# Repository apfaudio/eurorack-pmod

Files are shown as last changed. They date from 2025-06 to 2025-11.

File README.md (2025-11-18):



*Note: this repository contains Verilog examples for using Eurorack-PMOD with different FPGA boards. If you are trying to pair it with Tiliqua or Amaranth HDL, see the [quickstart guide there](https://apfaudio.github.io/tiliqua/quickstart/tlq_expander.html)*

# Eurorack PMOD

**Eurorack PMOD** is an [open hardware](https://certification.oshwa.org/de000135.html) Eurorack module that plugs directly into many FPGA boards, which makes it easy to combine the world of FPGAs and [hardware electronic music synthesis](https://en.wikipedia.org/wiki/Eurorack).

The hardware looks like this:



## How does it work? ([tutorial video](https://youtu.be/TcqFej9GK8U))
- Plug eurorack-pmod into an FPGA development board of your choice. Here is a list of [boards already supported by the examples](gateware/boards).
- Get started with some [example DSP cores](gateware/cores). Examples include calibration, sampling, effects, synthesis sources and so on. The design files can be synthesized to a bitstream using Yosys' [oss-cad-suite](https://github.com/YosysHQ/oss-cad-suite-build).

## :notes: Project Showcase :sparkles:

- **[FPGA-based neural-net waveshaper](https://matpalm.com/blog/wavenet_on_fpga/)** - (from [matpalm@](https://github.com/matpalm))
- **[Teensy 4.x I2S TDM w/ Eurorack PMOD](https://github.com/Lytrix/Teensy4-i2s-TDM)** - (from [lytrix@](https://github.com/Lytrix))
- **[8-channel USB2 soundcard](https://github.com/apfaudio/eurorack-pmod-usb-soundcard)** - mostly in Amaranth.
- **[Daisy Seed TDM for Eurorack PMOD](https://github.com/heartwerker/daisy_seed_tdm_eurorack_pmod)** - (from [heartwerker@](https://github.com/heartwerker))
- **[`apu_chord` core](https://github.com/proppy/eurorack-pmod/tree/apu_chord)** - (from [proppy@](https://github.com/proppy))
- **[Real-time DSP with Rust on LiteX](https://github.com/apfaudio/eurorack-pmod-litex)** - mostly in Rust/Migen.

# R3.5 hardware details

Some minor improvements over R3.3, with the following changes:
- Additional output mute stage: 4 JFETs controlled by the `^MUTE` pin (`PDN` pin was removed and renamed to `^MUTE` - semantics are the same as before - HIGH is unmuted).
- Improved noise performance and DC tracking by adding an additional onboard 3.3V regulator for the analog domain.
- Touch IC switched from 8-channel to 16-channel version, so that the XRESET pin is not shared with one of the touch jacks.

*Note: At this time, this Verilog repo is a bit out of date and refers to R3.3 everywhere, although I am shipping R3.5. The hardware is fully backward compatible besides the touch sensor mapping, so if you compile bitstreams for R3.3, they will work on R3.5. [See here for more details](https://apfaudio.github.io/tiliqua/quickstart/tlq_expander.html).*

# R3.3 hardware details

labelled eurorack-pmod 3.3

- 3HP module compatible with modular synthesizer systems.
    - Module depth is 35mm with both ribbon cables attached.
- [PMOD](https://en.wikipedia.org/wiki/Pmod_Interface) connector compatible with many FPGA development boards.
- 8 (4 in + 4 out) DC-coupled audio channels, 192KHz / 32bit sampling supported.
- PWM-controlled, user-programmable red/green LEDs on each output channel.
- Jack insertion detection on input & output jacks.
- Calibration EEPROM for unique ID and storing calibration data.
- [new!] Touch and proximity sensing on all unused jacks as an extra input method.
    - See the `gateware/cores/touch_cv.sv` core for an example of how to use this.

## Included examples
This repository contains a bunch of example DSP cores which are continuously being updated:
- `gateware/cores/pitch_shift.sv` - Pitch shifter
- `gateware/cores/filter.sv` - Filter (low pass + resonance)
- `gateware/cores/touch_cv.sv` - Touch sensing to CV converter
- `gateware/cores/clkdiv.sv` - Clock divider
- `gateware/cores/sampler.sv` - .wav sampler
- `gateware/cores/seqswitch.sv` - Sequential routing switch
- `gateware/cores/digital_echo.sv` - Echo / delay effect
- `gateware/cores/vca.sv` - VCA (voltage controlled amplifier)
- `gateware/cores/vco.sv` - VCO (voltage controlled oscillator)
- `gateware/cores/bitcrush.sv` - Bitcrusher

These examples can all run out of the box on the development boards listed below.

## Choosing an FPGA development board
An FPGA development board itself is NOT included! Essentially anything iCE40 or ECP5 based that has a PMOD connector will support the open-source tools and the examples in this project. Just make sure you have enough LUTS, >3K is enough to do interesting things.

The following development boards have been tested with `eurorack-pmod` and are supported by the examples in the github repository
- iCEbreaker (iCE40 based)
- [iCESugar](https://github.com/wuxx/icesugar) (iCE40 based, iCE40UP5K version)
- ECPIX-5 (ECP5 based)
- Colorlight i5 (ECP5 based)
- Colorlight i9 (ECP5 based)
- pico-ice from TinyVision (iCE40 based)
- CCGM1A1 Gatemate EVB from CologneChip - [**experimental!** see here](gateware/boards/gatemate_evb/README.md)

## PMOD Pinout

assembled eurorack-pmod module R3.3 (bottom)

The PMOD pinout is on the silkscreen on the back side of the board. Details are below. Note that Pin 1 is the SQUARE pad.

1) SDI (AK4619VN SDIN1)
2) SCL (I2C SCL for AK4619VN CODEC, EEPROM, LED + JACK IO expanders)
3) SDO (AK4619VN SDOUT1)
4) SDA (I2C SDA)
5) LRCK (CODEC clock line)
6) PDN (CODEC power down, also connected to LED output enable and JACK reset line -- HIGH means everything is on)
7) BICK (CODEC clock line)
8) MCLK (CODEC clock line)
9) GND
10) GND
11) 3V3 IN
12) 3V3 IN

## Getting Started

I have tested builds on Linux, Mac and Windows (under MSYS2). All are tested in CI.

0. Install the [OSS FPGA CAD flow](https://github.com/yosyshq/oss-cad-suite-build).
    - You may be able to get yosys / verilator from other package managers but I recommend using the [releases from YosysHQ](https://github.com/yosyshq/oss-cad-suite-build) so you're using the same binaries that CI is using.
    - On Linux, once the YosysHQ suite is installed and in PATH, you should be able to just use `make` in the gateware directory.
    - On Windows, CI is using MSYS2 with MINGW64 shell. Install MSYS2, MINGW64, extract the oss-cad-suite from YosysHQ and add it to PATH. Then you should be able to use `make` in the gateware directory.
    - Note: The gateware is automatically built and tested in CI, so for either platform it may be helpful to look at [`.github/workflows/main.yml`](.github/workflows/main.yml).

1. Build or obtain `eurorack-pmod` hardware and connect it to your FPGA development board using a ribbon cable or similar. (Double check that the pin mappings are correct, some ribbon cables will swap them on you! Default pinmaps are for the ribbon cables I shipped with hardware, you need to flip the pinmaps for a direct connection PMOD -> FPGA)
2. Try some of the examples. From the `gateware` directory, type `make` to see valid commands. By default if you do not select a CORE it will compile a bitstream with the 'mirror' core, which just sends inputs to outputs. Note, you'll need to run `git submodule update --init --recursive` from the repo root after checkout.
2. Calibrate your hardware using the process described in [`gateware/cal/cal.py`](gateware/cal/cal.py). Use this to create your own `gateware/cal/cal_mem.hex` to compensate for any DC biases in the ADCs/DACs. (this step is only necessary if you need sub-50mV accuracy on your inputs/outputs, which is the case if you are tuning oscillators, not so much if you are creating rhythm pulses.

# Project structure
The project is split into 2 directories, [`hardware`](hardware) for the PCB/panel and [`gateware`](gateware) for the FPGA source. Some interesting directories:
- [`gateware/cores`](gateware/cores): example user core implementations (i.e sequential switch, bitcrusher, filter, vco, vca, sampler etc).
- [`gateware/top.sv`](gateware/top.sv): top-level gateware with defines for selecting features.
- [`gateware/cal/cal.py`](gateware/cal/cal.py): tool used to calibrate the hardware after assembly, generating calibration memory.
- [`gateware/drivers`](gateware/drivers): driver for CODEC and I2C devices used on this board.
- [`hardware/eurorack-pmod-r3`](hardware/eurorack-pmod-r3): KiCAD design files for PCB and front panel.
- [`hardware/fab`](hardware/fab): gerber files and BOM for manufacturing the hardware.

# Manufacturing

# R3.1 Hardware (no longer manufactured)

The above README focuses on R3.3, which is currently being manufactured.

Revision R3.1 was sold out in 2023. It's no longer manufactured, however this repository still supports it if you use the `HW_REV=HW_R31` flag when building. I left some of the old photos here in case they are useful.

From the gateware perspective, there is almost no difference between R3.1 and R3.3 and so any cores should be compatible with both (unless they use new features of R3.3 e.g. touch sensitive jacks).

## R3.1 boards

assembled eurorack-pmod module R3.0 (panel)
assembled eurorack-pmod module R3.0 (top)

## R3.1 hardware details

labelled eurorack-pmod 3.0

## R3.1 technical

- 3HP module compatible with modular synthesizer systems.
    - Module depth is 47mm with both ribbon cables attached
    - This fits nicely in e.g. a 4MS POD 48X (pictured below).
- PMOD connector compatible with most FPGA development boards.
- 8 (4 in + 4 out) DC-coupled audio channels, 192KHz / 32bit sampling supported.
- PWM-controlled, user-programmable red/green LEDs on each output channel.
- Jack insertion detection on input & output jacks.
- Calibration EEPROM for unique ID and storing calibration data.
- I/O is about +/- 8V capable, wider is possible with a resistor change.

## Known limitations
- Moved to github issues

# Photos

## `eurorack-pmod` R3.1 connected to iCEBreaker
assembled eurorack-pmod module (in system)

# License

OSHW logo (https://certification.oshwa.org/de000135.html)

Hardware and gateware are released under the CERN Open-Hardware License V2 `CERN-OHL-S`, mirrored in the LICENSE text in this repository.

If you wish to license parts of this design in a commercial product without a reciprocal open-source license, or you have a ground-breaking idea for a module we could work on together, feel free to contact me directly. See sebholzapfel.com.

*Copyright (C) 2022-2024 Sebastian Holzapfel*

The above LICENSE and copyright notice does NOT apply to imported artifacts in this repository (i.e datasheets, third-party footprints).

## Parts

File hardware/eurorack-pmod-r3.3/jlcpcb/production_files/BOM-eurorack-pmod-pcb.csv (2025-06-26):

Comment | Designator | Footprint | LCSC | Quantity
2.2nF | C30 | C_0402_1005Metric | C106861 | 1
PCA9635 LED DRIVER | U10 | TSSOP-28_4.4x9.7mm_P0.65mm | C110795 | 1
56K | R19,R23,R27,R31 | R_0402_1005Metric | C114756 | 4
TCM809S (2.93V) | U6 | SOT-23 | C116736 | 1
22.0uF | C10,C11,C16,C28,C3,C4,C5,C9 | C_1206_3216Metric | C12891 | 8
PCA9557PW IO EXPANDER | U4 | TSSOP-16_4.4x5mm_P0.65mm | C141380 | 1
100nF | C1,C13,C14,C15,C17,C2,C29,C31,C32,C6,C8 | C_0603_1608Metric | C14663 | 11
FERRITE | L1,L2 | L_0603_1608Metric | C14709 | 2
220pF | C18,C19,C20,C21 | C_0402_1005Metric | C1530 | 4
24AA025UIDT EEPROM | U5 | SOT-23-6 | C2061498 | 1
Ceradiode 65V | RV1,RV2,RV3,RV4,RV5,RV6,RV7,RV8 | C_0603_1608Metric | C210791 | 8
1K | R10,R13,R16,R18,R22,R26,R30,R7 | R_0603_1608Metric | C21190 | 8
33R | R34 | R_0402_1005Metric | C25105 | 1
470R | R33 | R_0402_1005Metric | C25117 | 1
100K | R35 | R_0402_1005Metric | C25741 | 1
10K | R36 | R_0402_1005Metric | C25744 | 1
100K | R12,R15,R37,R38,R39,R40,R6,R9 | R_0603_1608Metric | C25803 | 8
4K7 | R1,R11,R14,R17,R2,R20,R21,R24,R25,R28,R29,R3,R32,R4,R5,R8 | R_0402_1005Metric | C25900 | 16
VBUS05L1 | D27,D28,D29,D30,D31,D32,D33,D34 | VISHAY-LLP1006-2M | C2649891 | 8
MMBFJ111 | Q2,Q3,Q4,Q5 | SOT-23 | C274688 | 4
1uF | C33 | C_0805_2012Metric | C28323 | 1
AUDIO JACK PJ-324M0 | J10,J11,J4,J5,J6,J7,J8,J9 | pj324m | C2884986 | 8
AK4619VN AUDIO CODEC | U1 | QFN-32-1EP_5x5mm_P0.5mm_EP3.7x3.7mm_ThermalVias | C3034747 | 1
100K | RN5,RN6,RN7 | R_Array_Convex_4x0402 | C326786 | 3
120R | RN10,RN11,RN8,RN9 | R_Array_Convex_4x0402 | C326871 | 4
LTV-357T | U11 | SO-4_4.4x3.6mm_P2.54mm | C33068 | 1
AZ1117-3.3 | U8 | SOT-89-3 | C460428 | 1
Nexperia PMEG6010CEH,115 | D1,D2 | D_SOD-123F | C493190 | 2
2.2uF | C12,C7 | C_1206_3216Metric | C50254 | 2
56p | C22,C23,C24,C25 | C_0402_1005Metric | C526981 | 4
Conn_01x14_Socket | J3 | FFC_0.5-14P_CTXJ-H2.0_1 | C5373472 | 1
560R | RN12,RN13 | R_Array_Convex_4x0402 | C695210 | 2
TL072 OP AMP | U9 | SOIC-8_3.9x4.9mm_P1.27mm | C6961 | 1
TL074 OP AMP | U2,U3 | SOIC-14_3.9x8.7mm_P1.27mm | C6963 | 2
2N7002E | Q1 | SOT-23 | C71533 | 1
14.3K | RN1,RN2,RN3,RN4 | R_Array_Convex_4x0402 | C728708 | 4
15V 200mA | F2,F3 | Fuse_0805_2012Metric | C883103 | 2
CY8CMBR3116 | U7 | QFN-24-1EP_4x4mm_P0.5mm_EP2.6x2.6mm | C914913 | 1
LED 0402 RED | D10,D12,D14,D16,D18,D4,D6,D8 | LED_0402_1005Metric | C965790 | 8
LED 0402 GREEN | D11,D13,D15,D17,D3,D5,D7,D9 | LED_0402_1005Metric | C965793 | 8

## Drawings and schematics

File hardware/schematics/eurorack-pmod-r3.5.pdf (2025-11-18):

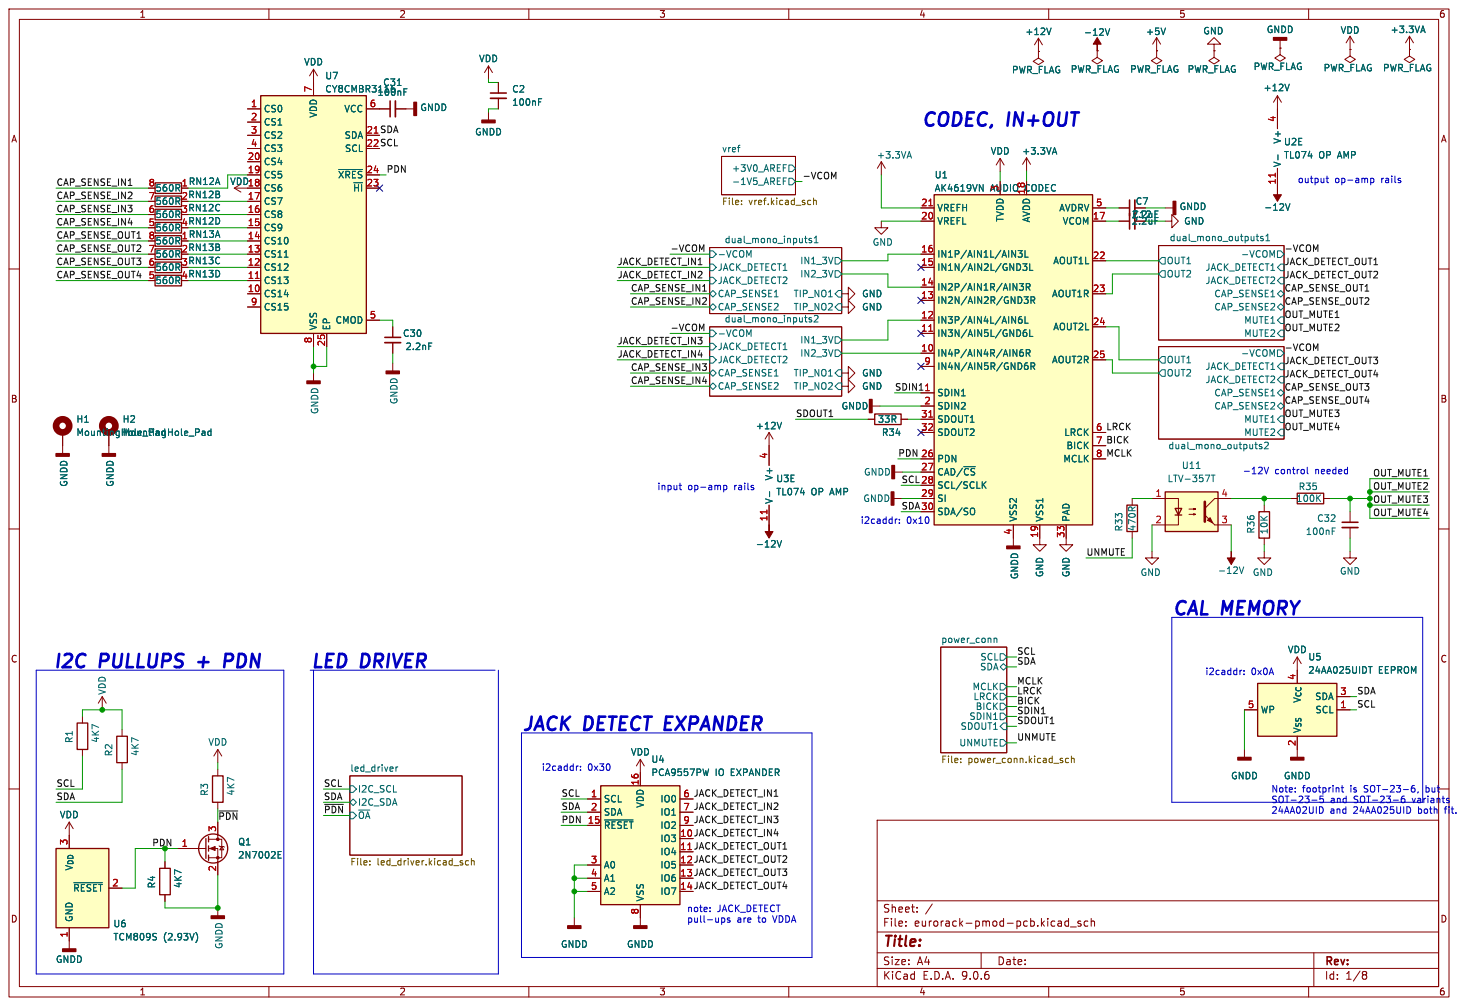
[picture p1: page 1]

8 EP 25 VCC 6 SDA 21 SCL 22 ~{XRES} 24 ~{HI}23 CMOD 5 U7 CY8CMBR3116C31

8 EP 25 VCC 6 SDA 21 SCL 22 ~{XRES} 24 ~{HI}23 CMOD 5 C31

4 AVDD 18 VSS1 19 PAD 33 AVDRV 5 VCOM 17 AOUT1L 22 AOUT1R 23 AOUT2L 24 AOUT2R 25

dual_mono_outputs1 SCL SDA UNMUTE MCLK

TL074 OP AMP GNDD GNDD
TL074 OP AMP V+

Id: 1/8 Title: File: eurorack-pmod-pcb.kicad_sch Sheet: /

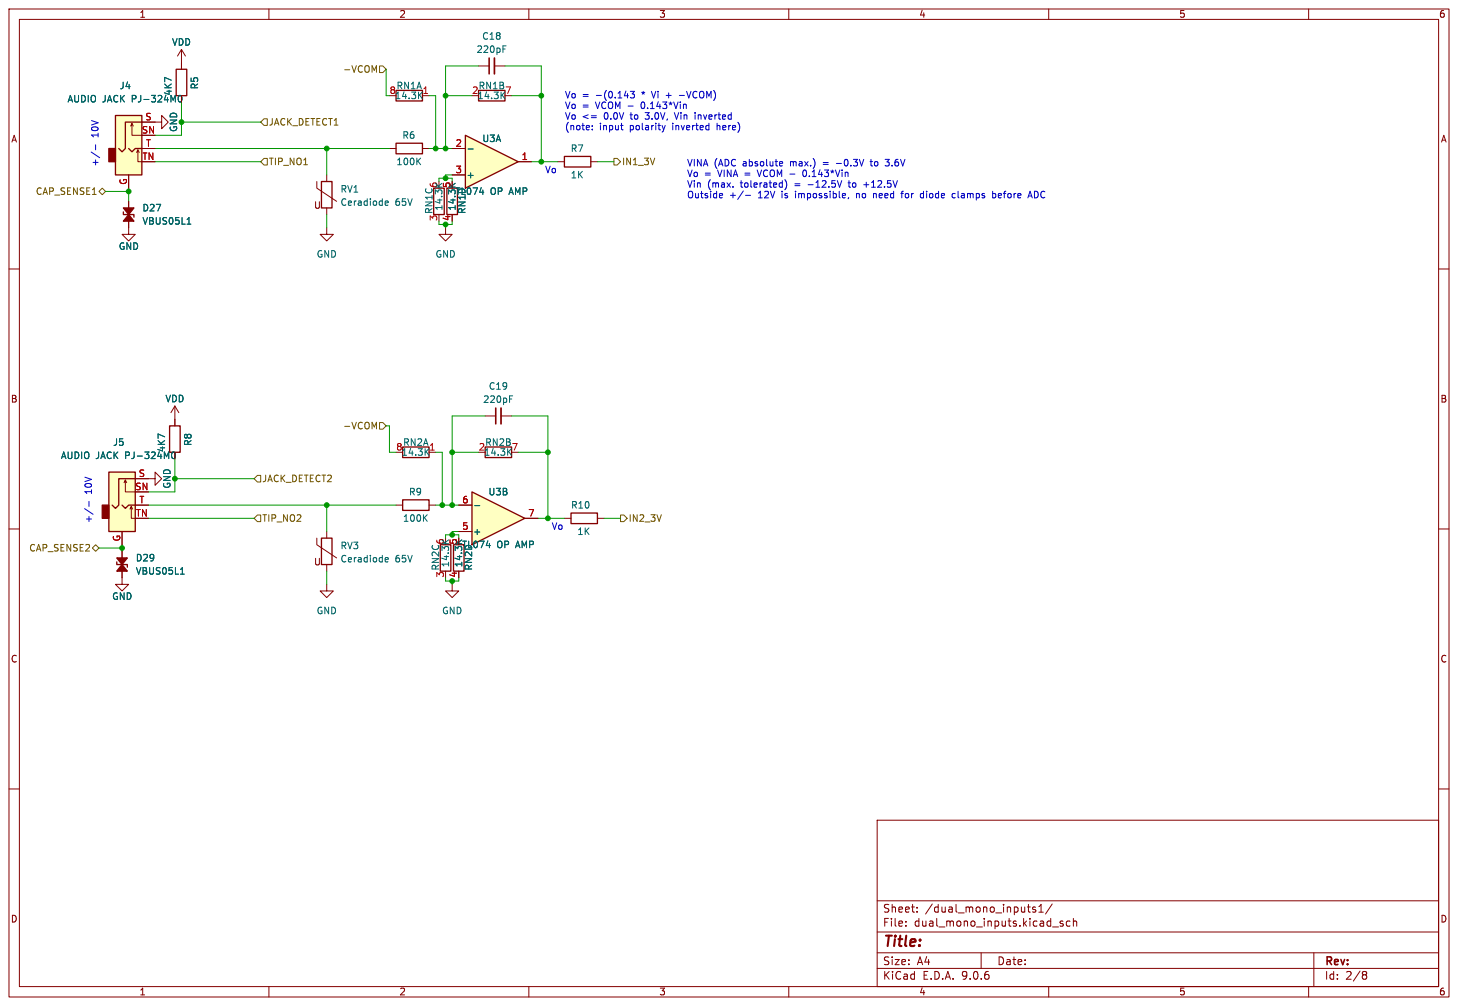
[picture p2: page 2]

Id: 2/8 Title: File: dual_mono_inputs.kicad_sch Sheet: /dual_mono_inputs1/

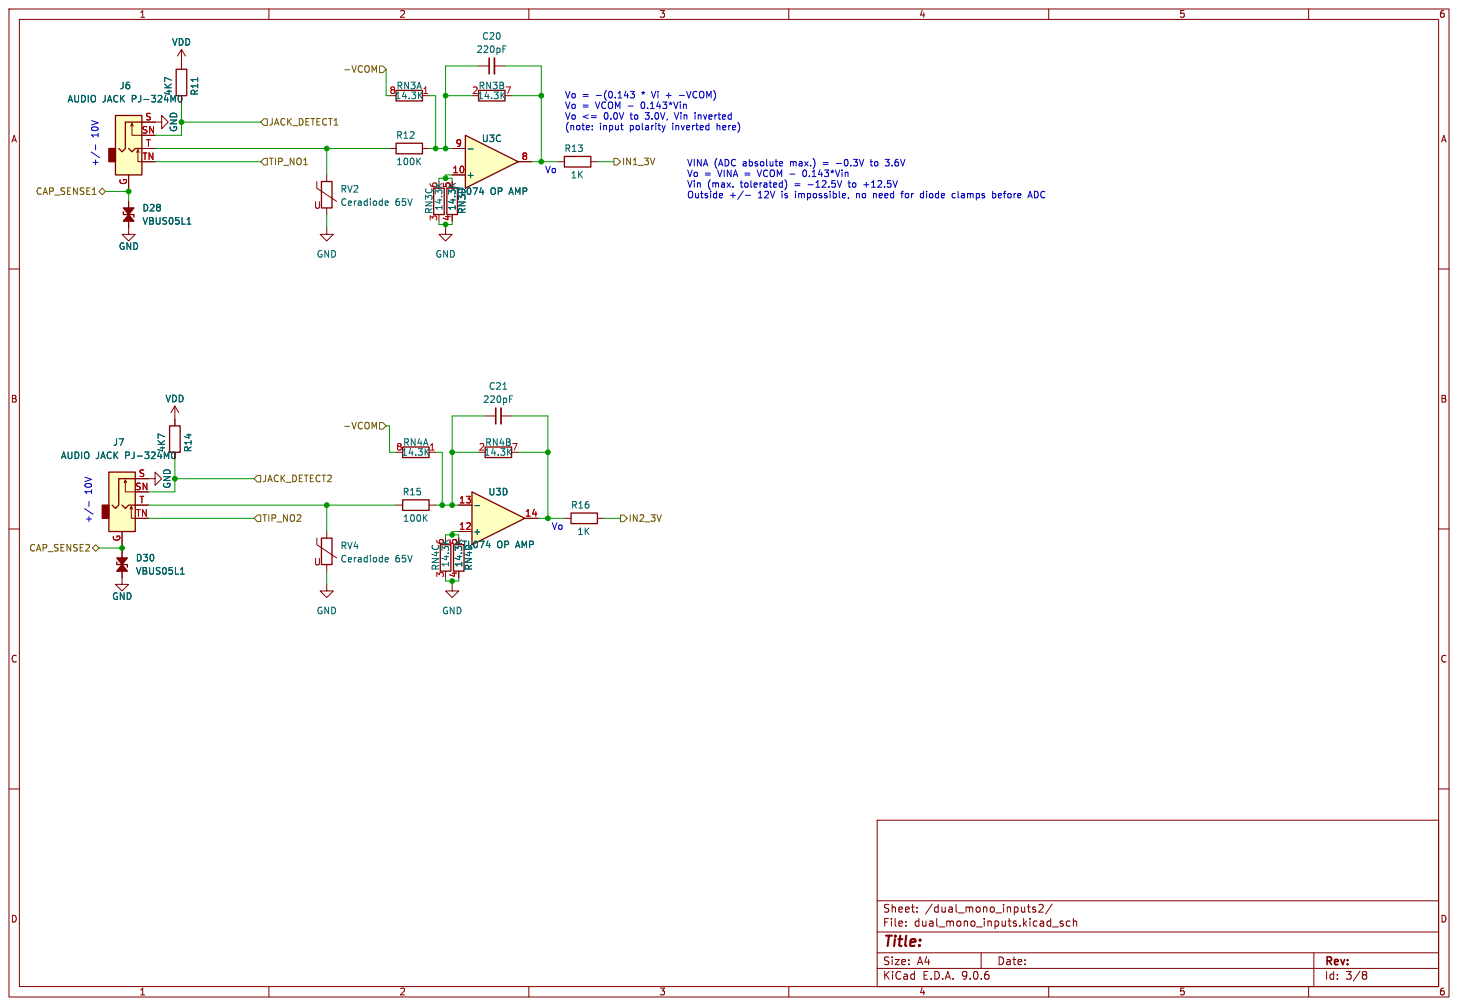
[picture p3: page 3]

Id: 3/8 Title: File: dual_mono_inputs.kicad_sch Sheet: /dual_mono_inputs2/

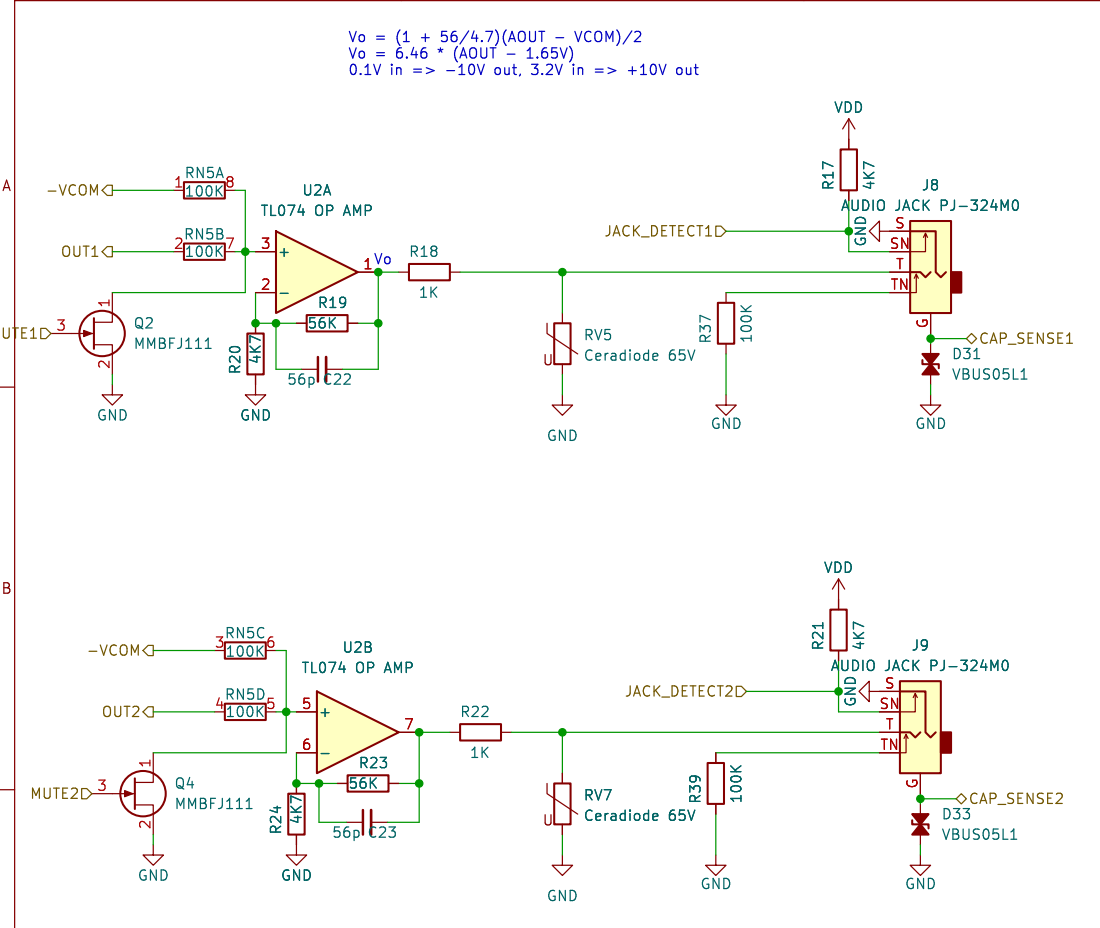
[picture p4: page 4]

Id: 4/8 Title: File: dual_mono_outputs.kicad_sch Sheet: /dual_mono_outputs1/

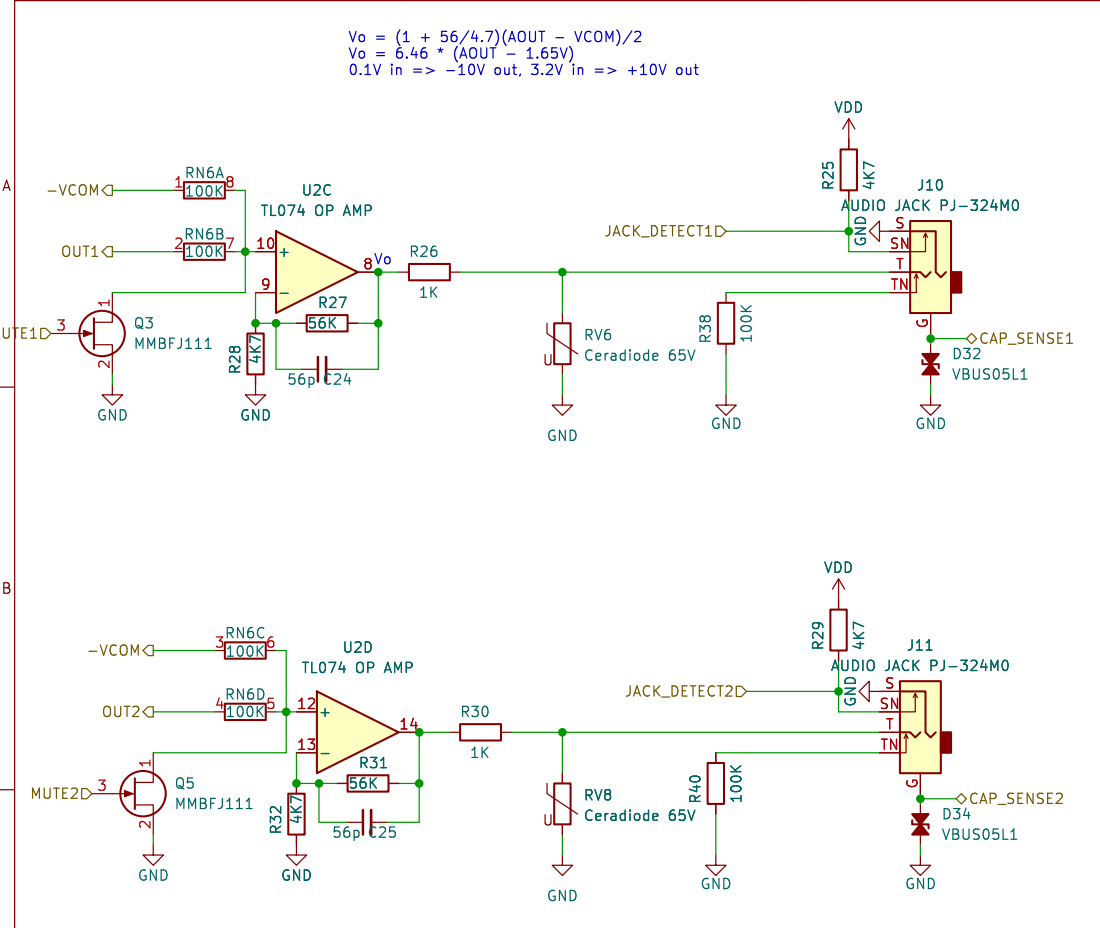
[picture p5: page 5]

Id: 5/8 Title: File: dual_mono_outputs.kicad_sch Sheet: /dual_mono_outputs2/

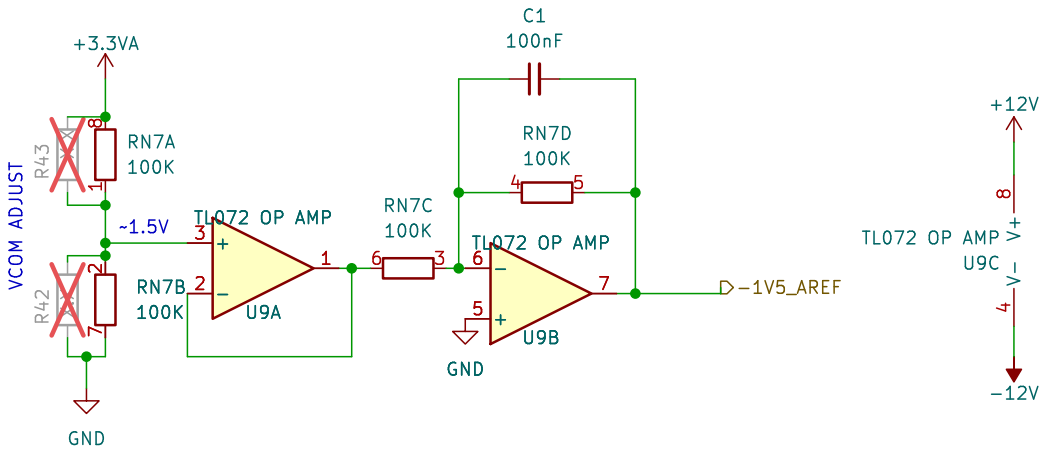
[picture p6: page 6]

Id: 6/8 Title: File: vref.kicad_sch Sheet: /vref/

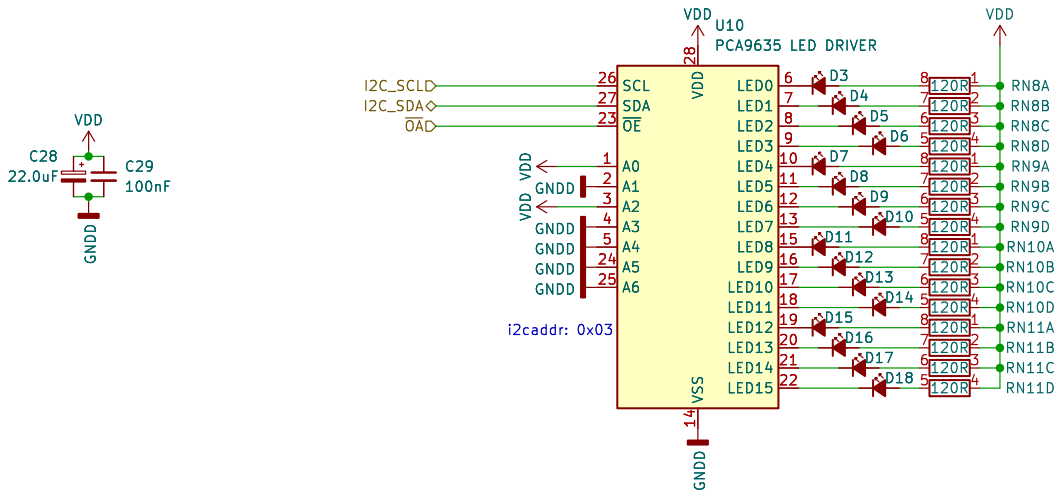
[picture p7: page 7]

Id: 7/8 Title: File: led_driver.kicad_sch Sheet: /led_driver/

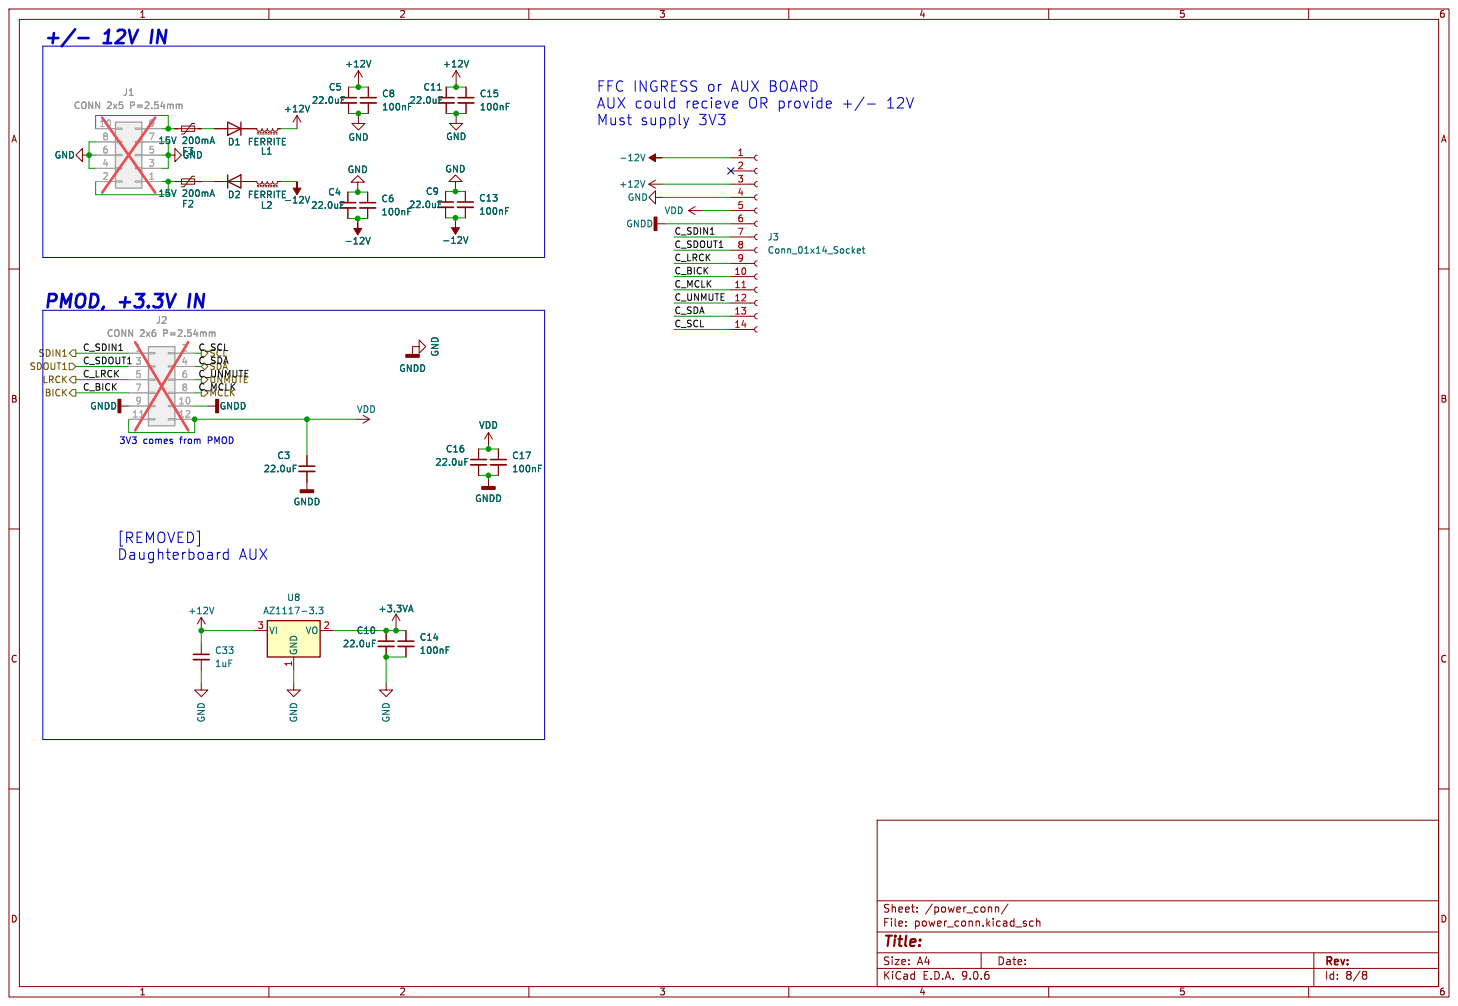
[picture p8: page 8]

FFC INGRESS or AUX BOARD
Must supply 3V3
-12VGND GNDD

Id: 8/8 Title: File: power_conn.kicad_sch Sheet: /power_conn/

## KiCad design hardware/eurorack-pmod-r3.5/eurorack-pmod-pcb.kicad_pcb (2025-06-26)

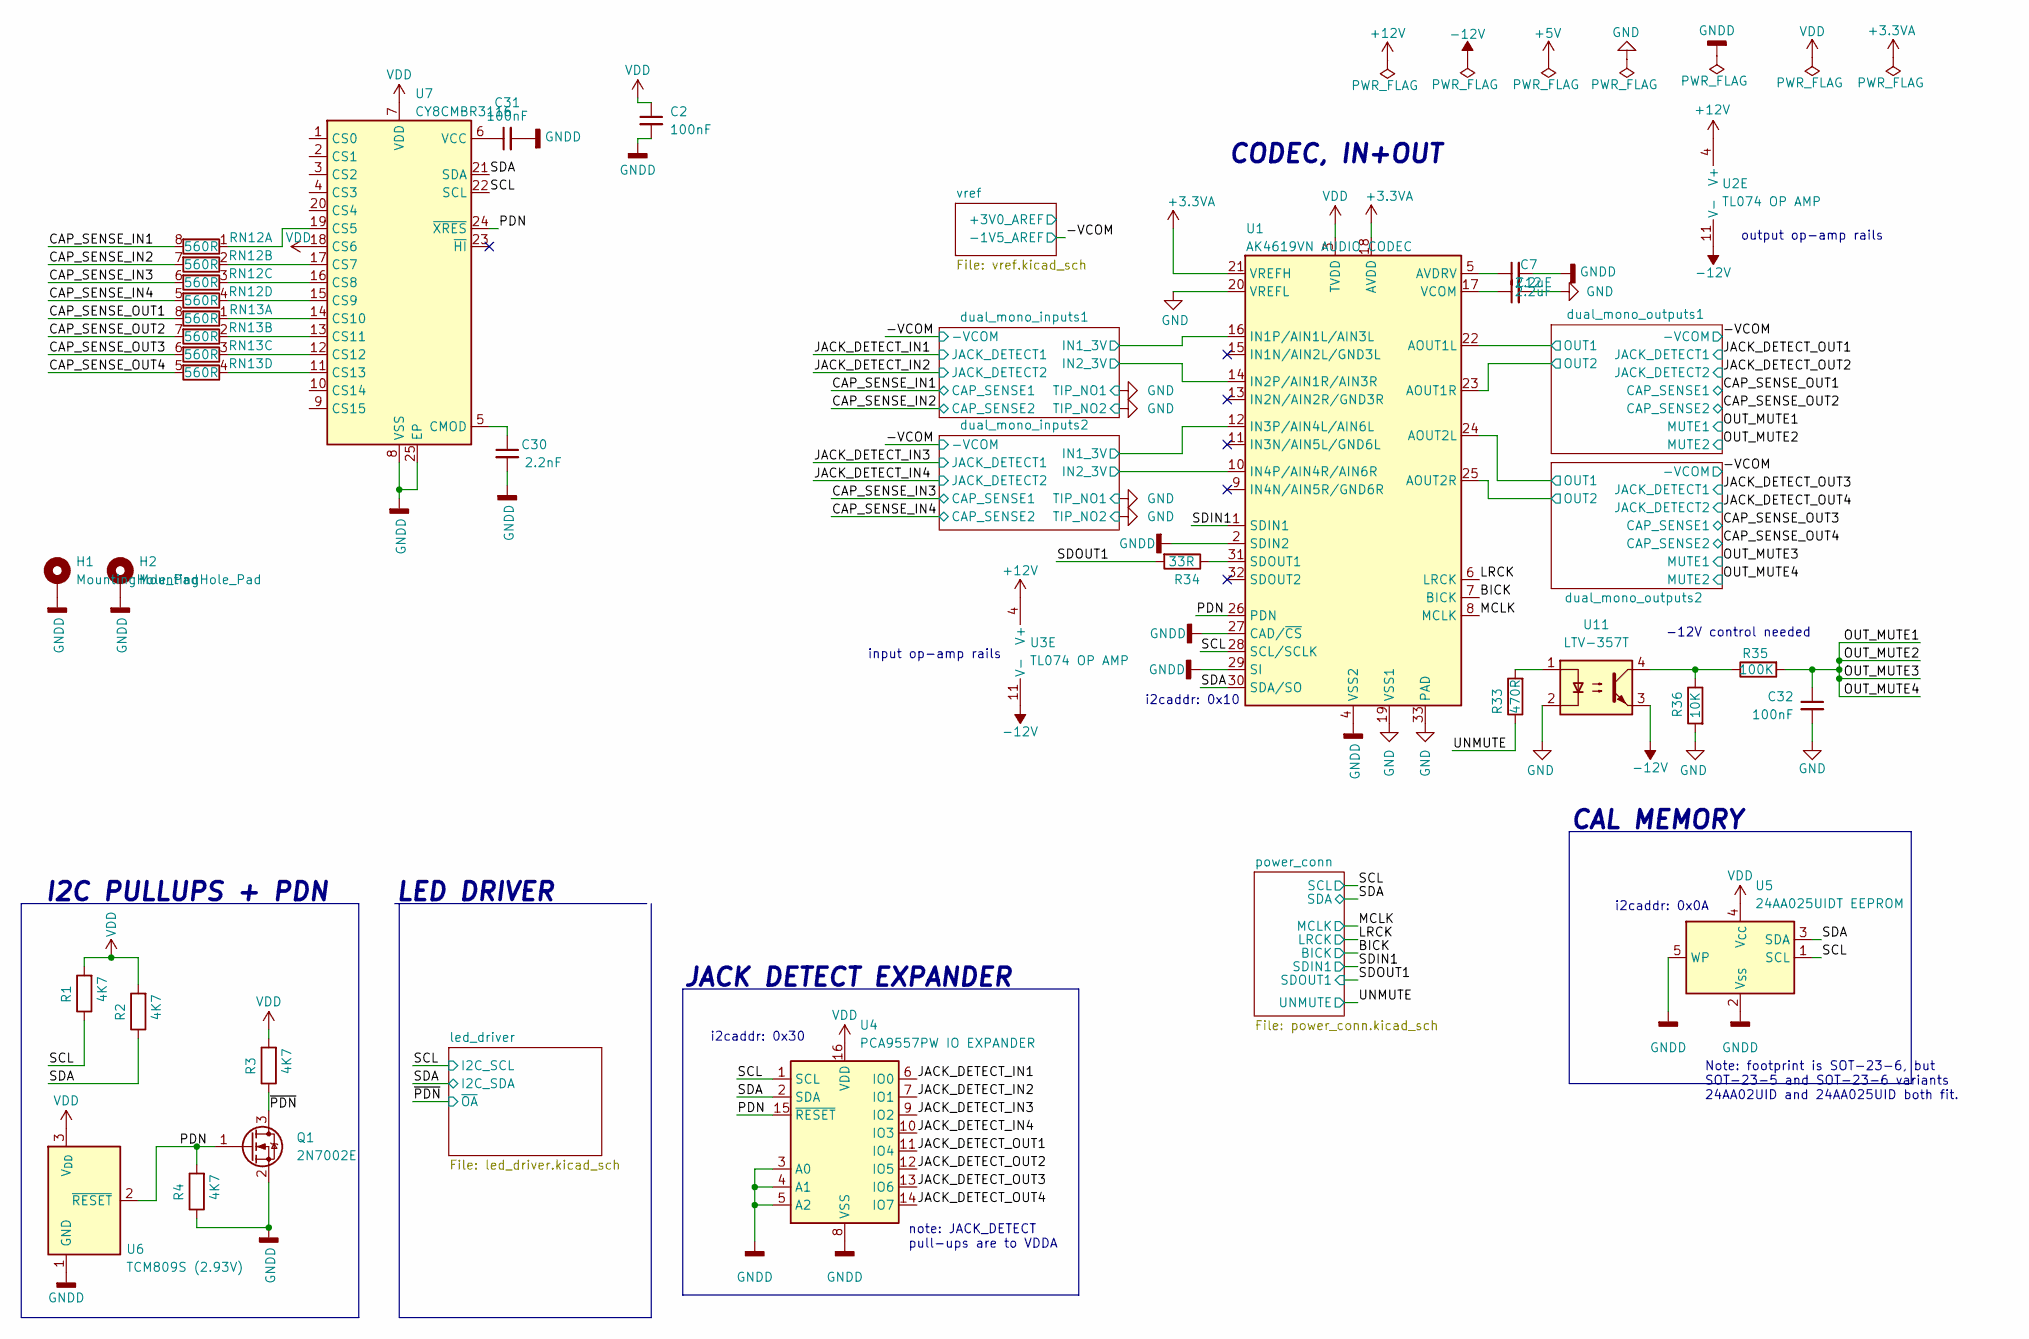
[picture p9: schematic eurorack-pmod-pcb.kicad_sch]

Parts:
C2, C31, C32: 100nF; C_0603_1608Metric; mfg# C1608X7R1E104KT000N; lcsc# C338036
C7, C12: 2.2uF; C_1206_3216Metric; lcsc# C377799
C30: 2.2nF; C_0402_1005Metric; mfg# CC0402KRX7R9BB222; lcsc# C106861
H1, H2: MountingHole_Pad
Q1: 2N7002E; SOT-23; mfg# 2N7002ET1G; lcsc# C71533
R1, R2, R3, R4: 4K7; R_0402_1005Metric; mfg# RC0402FR-074K7L; lcsc# C105871
R33: 470R; R_0402_1005Metric; LCSC C25117
R34: 33R; R_0402_1005Metric; LCSC C25105
R35: 100K; R_0402_1005Metric; LCSC C25741
R36: 10K; R_0402_1005Metric; LCSC C25744
RN12, RN13: 560R; R_Array_Convex_4x0402; mfg# YC124-JR-07560RL; lcsc# C695210
U1: AK4619VN AUDIO CODEC; QFN-32-1EP_5x5mm_P0.5mm_EP3.7x3.7mm_ThermalVias; mfg# AK4619VN; lcsc# AK4619VN
U2, U3: TL074 OP AMP; SOIC-14_3.9x8.7mm_P1.27mm; mfg# TL074CDT; lcsc# C6963
U4: PCA9557PW IO EXPANDER; TSSOP-16_4.4x5mm_P0.65mm; mfg# PCA9557PW,118; lcsc# C141380
U5: 24AA025UIDT EEPROM; SOT-23-6; mfg# 24AA025UIDT-I/OT; lcsc# C2061498
U6: TCM809S (2.93V); SOT-23; lcsc# C116736
U7: CY8CMBR3116; QFN-24-1EP_4x4mm_P0.5mm_EP2.6x2.6mm; lcsc# C914913
U11: LTV-357T; SO-4_4.4x3.6mm_P2.54mm; LCSC C33068

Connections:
+3.3VA: U1.18 (AVDD), U1.21 (VREFH); also elsewhere on the board
+12V: U2.4 (V+), U3.4 (V+); also elsewhere on the board
-12V: U2.11 (V-), U3.11 (V-), U11.3; also elsewhere on the board
/BICK: U1.7 (BICK); also elsewhere on the board
/CAP_SENSE_IN1: RN12.8 (R1.2); also elsewhere on the board
/CAP_SENSE_IN2: RN12.7 (R2.2); also elsewhere on the board
/CAP_SENSE_IN3: RN12.6 (R3.2); also elsewhere on the board
/CAP_SENSE_IN4: RN12.5 (R4.2); also elsewhere on the board
/CAP_SENSE_OUT1: RN13.8 (R1.2); also elsewhere on the board
/CAP_SENSE_OUT2: RN13.7 (R2.2); also elsewhere on the board
/CAP_SENSE_OUT3: RN13.6 (R3.2); also elsewhere on the board
/CAP_SENSE_OUT4: RN13.5 (R4.2); also elsewhere on the board
/JACK_DETECT_IN1: U4.6 (IO0); also elsewhere on the board
/JACK_DETECT_IN2: U4.7 (IO1); also elsewhere on the board
/JACK_DETECT_IN3: U4.9 (IO2); also elsewhere on the board
/JACK_DETECT_IN4: U4.10 (IO3); also elsewhere on the board
/JACK_DETECT_OUT1: U4.11 (IO4); also elsewhere on the board
/JACK_DETECT_OUT2: U4.12 (IO5); also elsewhere on the board
/JACK_DETECT_OUT3: U4.13 (IO6); also elsewhere on the board
/JACK_DETECT_OUT4: U4.14 (IO7); also elsewhere on the board
/LRCK: U1.6 (LRCK); also elsewhere on the board
/MCLK: U1.8 (MCLK); also elsewhere on the board
/OUT_MUTE1: C32.1, R35.2; also elsewhere on the board
/PDN: Q1.1 (G), R4.2, U1.26 (PDN), U4.15 (~RESET), U6.2 (~RESET), U7.24 (~XRES)
/SCL: R1.1, U1.28 (SCL/SCLK), U4.1 (SCL), U5.1 (SCL), U7.22 (SCL); also elsewhere on the board
/SDA: R2.1, U1.30 (SDA/SO), U4.2 (SDA), U5.3 (SDA), U7.21 (SDA); also elsewhere on the board
/SDIN1: U1.1 (SDIN1); also elsewhere on the board
/SDOUT1: R34.2; also elsewhere on the board
/UNMUTE: R33.1; also elsewhere on the board
/dual_mono_inputs1/IN1_3V: U1.16 (IN1P/AIN1L/AIN3L); also elsewhere on the board
/dual_mono_inputs1/IN2_3V: U1.14 (IN2P/AIN1R/AIN3R); also elsewhere on the board
/dual_mono_inputs2/IN1_3V: U1.12 (IN3P/AIN4L/AIN6L); also elsewhere on the board
/dual_mono_inputs2/IN2_3V: U1.10 (IN4P/AIN4R/AIN6R); also elsewhere on the board
/dual_mono_outputs1/OUT1: U1.22 (AOUT1L); also elsewhere on the board
/dual_mono_outputs1/OUT2: U1.23 (AOUT1R); also elsewhere on the board
/dual_mono_outputs2/OUT1: U1.24 (AOUT2L); also elsewhere on the board
/dual_mono_outputs2/OUT2: U1.25 (AOUT2R); also elsewhere on the board
/~PDN: Q1.3 (D), R3.1; also elsewhere on the board
GND: C2.2, C7.2, C12.2, C30.2, C31.2, C32.2, H1.1, H2.1, Q1.2 (S), R4.1, R36.2, U1.2 (SDIN2), U1.4 (VSS2), U1.19 (VSS1), U1.20 (VREFL), U1.27 (CAD/~CS), U1.29 (SI), U1.33 (PAD), U4.3 (A0), U4.4 (A1), U4.5 (A2), U4.8 (VSS), U5.2 (V_{SS}), U5.5 (WP), U6.1 (GND), U7.8 (VSS), U7.25 (EP), U11.2; also elsewhere on the board
unnamed 42: U2.8; also elsewhere on the board
unnamed 43: U2.14; also elsewhere on the board
unnamed 95: U2.10 (+); also elsewhere on the board
unnamed 97: U2.12 (+); also elsewhere on the board
unnamed: R33.2, U11.1
unnamed: R35.1, R36.1, U11.4
unnamed 106: U3.9 (-); also elsewhere on the board
unnamed 107: U3.8; also elsewhere on the board
unnamed 108: U3.10 (+); also elsewhere on the board
unnamed 109: U3.13 (-); also elsewhere on the board
unnamed 110: U3.14; also elsewhere on the board
unnamed 111: U3.12 (+); also elsewhere on the board
unnamed: RN12.1 (R1.1), U7.19 (CS5)
unnamed: RN12.2 (R2.1), U7.17 (CS7)
unnamed: RN12.3 (R3.1), U7.16 (CS8)
unnamed: RN12.4 (R4.1), U7.15 (CS9)
unnamed: RN13.1 (R1.1), U7.14 (CS10)
unnamed: RN13.2 (R2.1), U7.13 (CS11)
unnamed: RN13.3 (R3.1), U7.12 (CS12)
unnamed: RN13.4 (R4.1), U7.11 (CS13)
unnamed: C7.1, U1.5 (AVDRV)
unnamed: R34.1, U1.31 (SDOUT1)
unnamed: C12.1, U1.17 (VCOM)
unnamed 128: U2.9 (-); also elsewhere on the board
unnamed 129: U2.13 (-); also elsewhere on the board
unnamed: C30.1, U7.5 (CMOD)
unnamed: C31.1, U7.6 (VCC)
VDD: C2.1, R1.2, R2.2, R3.2, U1.3 (TVDD), U4.16 (VDD), U5.4 (V_{CC}), U6.3 (V_{DD}), U7.7 (VDD), U7.18 (CS6); also elsewhere on the board

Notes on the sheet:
CAL MEMORY
Note: footprint is SOT-23-6, but SOT-23-5 and SOT-23-6 variants 24AA02UID and 24AA025UID both fit.
i2caddr: 0x10
I2C PULLUPS + PDN
i2caddr: 0x30
input op-amp rails
note: JACK_DETECT pull-ups are to VDDA
JACK DETECT EXPANDER
LED DRIVER
output op-amp rails
CODEC, IN+OUT
-12V control needed
i2caddr: 0x0A

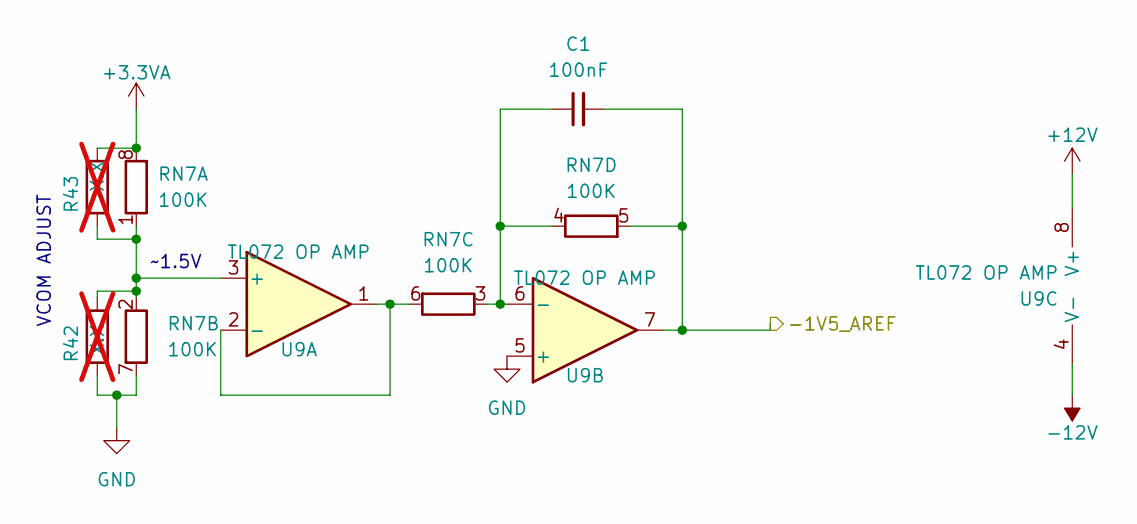
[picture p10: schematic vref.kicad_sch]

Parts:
C1: 100nF; C_0603_1608Metric; mfg# C1608X7R1E104KT000N; lcsc# C338036
R42, R43: X.X; R_0402_1005Metric; not fitted
RN7: 100K; R_Array_Convex_4x0402; mfg# YC124-FR-07100KL; lcsc# C326786
U9: TL072 OP AMP; SOIC-8_3.9x4.9mm_P1.27mm; mfg# TL072CDT; lcsc# C6961

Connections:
+3.3VA: R43.2, RN7.8 (R1.2); also elsewhere on the board
+12V: U9.8 (V+); also elsewhere on the board
-12V: U9.4 (V-); also elsewhere on the board
/-VCOM: C1.2, RN7.5 (R4.2), U9.7; also elsewhere on the board
GND: R42.1, RN7.7 (R2.2), U9.5 (+); also elsewhere on the board
unnamed: R42.2, R43.1, RN7.1 (R1.1), RN7.2 (R2.1), U9.3 (+)
unnamed: C1.1, RN7.3 (R3.1), RN7.4 (R4.1), U9.6 (-)
unnamed: RN7.6 (R3.2), U9.1, U9.2 (-)

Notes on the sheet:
~1.5V
VCOM ADJUST

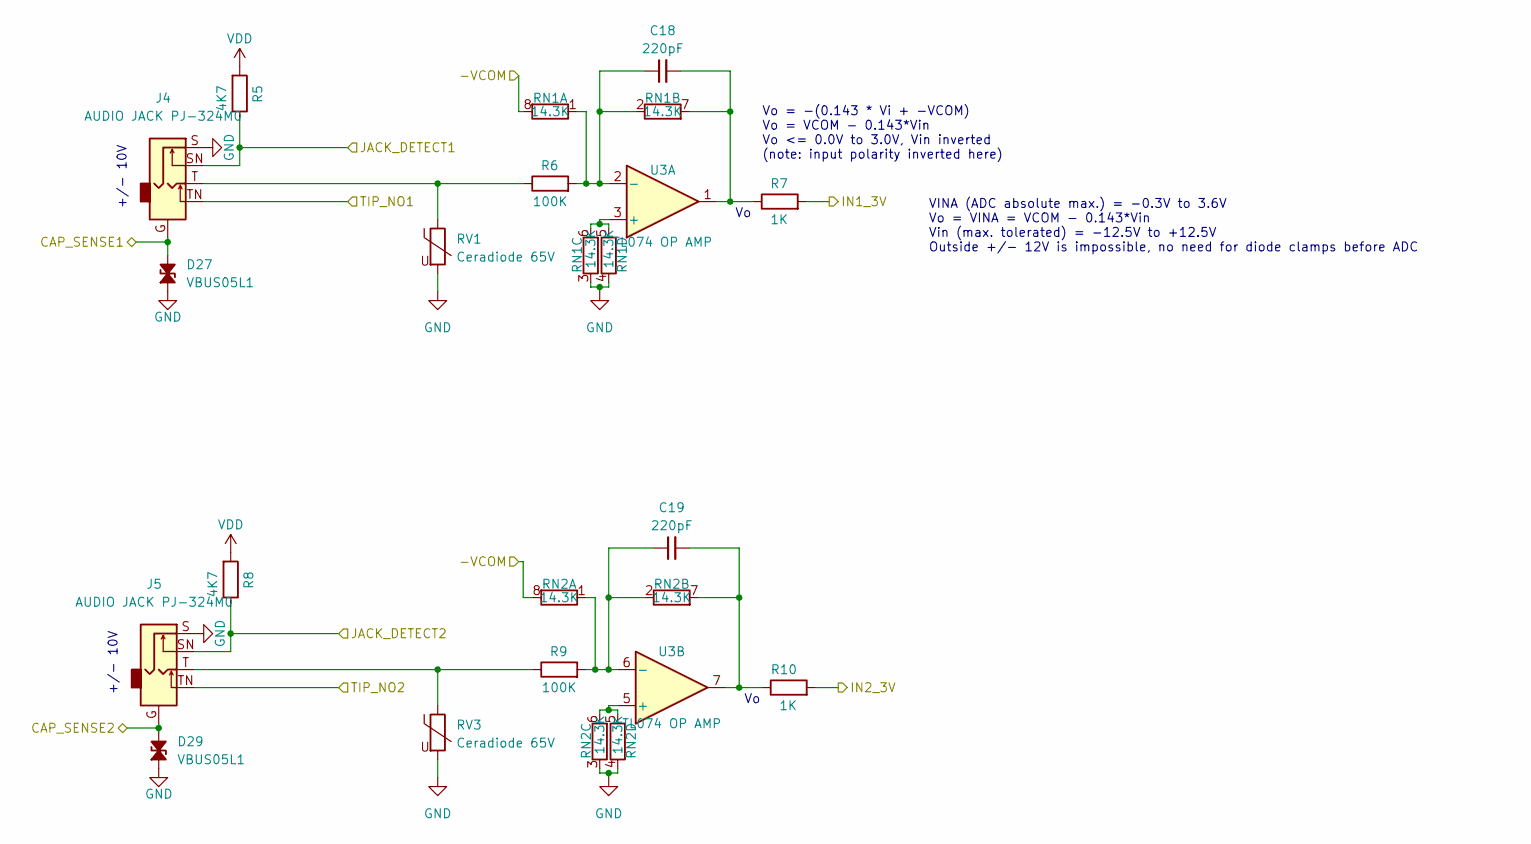
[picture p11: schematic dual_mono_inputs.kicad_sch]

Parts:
C18, C19: 220pF; C_0402_1005Metric; mfg# GRM1555C1H221JA01D; lcsc# C71693
D27, D29: VBUS05L1; VISHAY-LLP1006-2M; lcsc# C2649891
J4, J5: AUDIO JACK PJ-324M0; pj324m; mfg# PJ-324M0; lcsc# C2884986
R5, R8: 4K7; R_0402_1005Metric; mfg# RC0402FR-074K7L; lcsc# C105871
R6, R9: 100K; R_0603_1608Metric; mfg# RC0603FR-07100KL; lcsc# C14675
R7, R10: 1K; R_0603_1608Metric; mfg# RC0603FR-071KL; lcsc# C22548
RN1, RN2: 14.3K; R_Array_Convex_4x0402; mfg# YC124-FR-0714K3L; lcsc# C728708
RV1, RV3: Ceradiode 65V; C_0603_1608Metric; lcsc# C210791
U3: TL074 OP AMP; SOIC-14_3.9x8.7mm_P1.27mm; mfg# TL074CDT; lcsc# C6963

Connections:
/-VCOM: RN1.8 (R1.2), RN2.8 (R1.2); also elsewhere on the board
/CAP_SENSE_IN1: D27.2 (A2), J4.G; also elsewhere on the board
/CAP_SENSE_IN2: D29.2 (A2), J5.G; also elsewhere on the board
/JACK_DETECT_IN1: J4.SN, R5.1; also elsewhere on the board
/JACK_DETECT_IN2: J5.SN, R8.1; also elsewhere on the board
/dual_mono_inputs1/IN1_3V: R7.2; also elsewhere on the board
/dual_mono_inputs1/IN2_3V: R10.2; also elsewhere on the board
GND: D27.1 (A1), D29.1 (A1), J4.S, J4.TN, J5.S, J5.TN, RN1.3 (R3.1), RN1.4 (R4.1), RN2.3 (R3.1), RN2.4 (R4.1), RV1.2, RV3.2; also elsewhere on the board
unnamed: J4.T, R6.1, RV1.1
unnamed: J5.T, R9.1, RV3.1
unnamed: C18.1, R6.2, RN1.1 (R1.1), RN1.2 (R2.1), U3.2 (-)
unnamed: C18.2, R7.1, RN1.7 (R2.2), U3.1
unnamed: RN1.5 (R4.2), RN1.6 (R3.2), U3.3 (+)
unnamed: C19.1, R9.2, RN2.1 (R1.1), RN2.2 (R2.1), U3.6 (-)
unnamed: C19.2, R10.1, RN2.7 (R2.2), U3.7
unnamed: RN2.5 (R4.2), RN2.6 (R3.2), U3.5 (+)
unnamed 106: U3.9 (-); also elsewhere on the board
unnamed 107: U3.8; also elsewhere on the board
unnamed 108: U3.10 (+); also elsewhere on the board
unnamed 109: U3.13 (-); also elsewhere on the board
unnamed 110: U3.14; also elsewhere on the board
unnamed 111: U3.12 (+); also elsewhere on the board
VDD: R5.2, R8.2; also elsewhere on the board

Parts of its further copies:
C20, C21: 220pF; C_0402_1005Metric; mfg# GRM1555C1H221JA01D; lcsc# C71693
D28, D30: VBUS05L1; VISHAY-LLP1006-2M; lcsc# C2649891
J6, J7: AUDIO JACK PJ-324M0; pj324m; mfg# PJ-324M0; lcsc# C2884986
R11, R14: 4K7; R_0402_1005Metric; mfg# RC0402FR-074K7L; lcsc# C105871
R12, R15: 100K; R_0603_1608Metric; mfg# RC0603FR-07100KL; lcsc# C14675
R13, R16: 1K; R_0603_1608Metric; mfg# RC0603FR-071KL; lcsc# C22548
RN3, RN4: 14.3K; R_Array_Convex_4x0402; mfg# YC124-FR-0714K3L; lcsc# C728708
RV2, RV4: Ceradiode 65V; C_0603_1608Metric; lcsc# C210791

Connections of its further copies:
/-VCOM: RN3.8 (R1.2), RN4.8 (R1.2); also elsewhere on the board
/CAP_SENSE_IN3: D28.2 (A2), J6.G; also elsewhere on the board
/CAP_SENSE_IN4: D30.2 (A2), J7.G; also elsewhere on the board
/JACK_DETECT_IN3: J6.SN, R11.1; also elsewhere on the board
/JACK_DETECT_IN4: J7.SN, R14.1; also elsewhere on the board
/dual_mono_inputs2/IN1_3V: R13.2; also elsewhere on the board
/dual_mono_inputs2/IN2_3V: R16.2; also elsewhere on the board
GND: D28.1 (A1), D30.1 (A1), J6.S, J6.TN, J7.S, J7.TN, RN3.3 (R3.1), RN3.4 (R4.1), RN4.3 (R3.1), RN4.4 (R4.1), RV2.2, RV4.2; also elsewhere on the board
unnamed: J6.T, R12.1, RV2.1
unnamed: J7.T, R15.1, RV4.1
unnamed 106: C20.1, R12.2, RN3.1 (R1.1), RN3.2 (R2.1); also elsewhere on the board
unnamed 107: C20.2, R13.1, RN3.7 (R2.2); also elsewhere on the board
unnamed 108: RN3.5 (R4.2), RN3.6 (R3.2); also elsewhere on the board
unnamed 109: C21.1, R15.2, RN4.1 (R1.1), RN4.2 (R2.1); also elsewhere on the board
unnamed 110: C21.2, R16.1, RN4.7 (R2.2); also elsewhere on the board
unnamed 111: RN4.5 (R4.2), RN4.6 (R3.2); also elsewhere on the board
VDD: R11.2, R14.2; also elsewhere on the board

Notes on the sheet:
+/- 10V
Vo = -(0.143 * Vi + -VCOM) Vo = VCOM - 0.143*Vin Vo <= 0.0V to 3.0V, Vin inverted (note: input polarity inverted here)
VINA (ADC absolute max.) = -0.3V to 3.6V Vo = VINA = VCOM - 0.143*Vin Vin (max. tolerated) = -12.5V to +12.5V Outside +/- 12V is impossible, no need for diode clamps before ADC

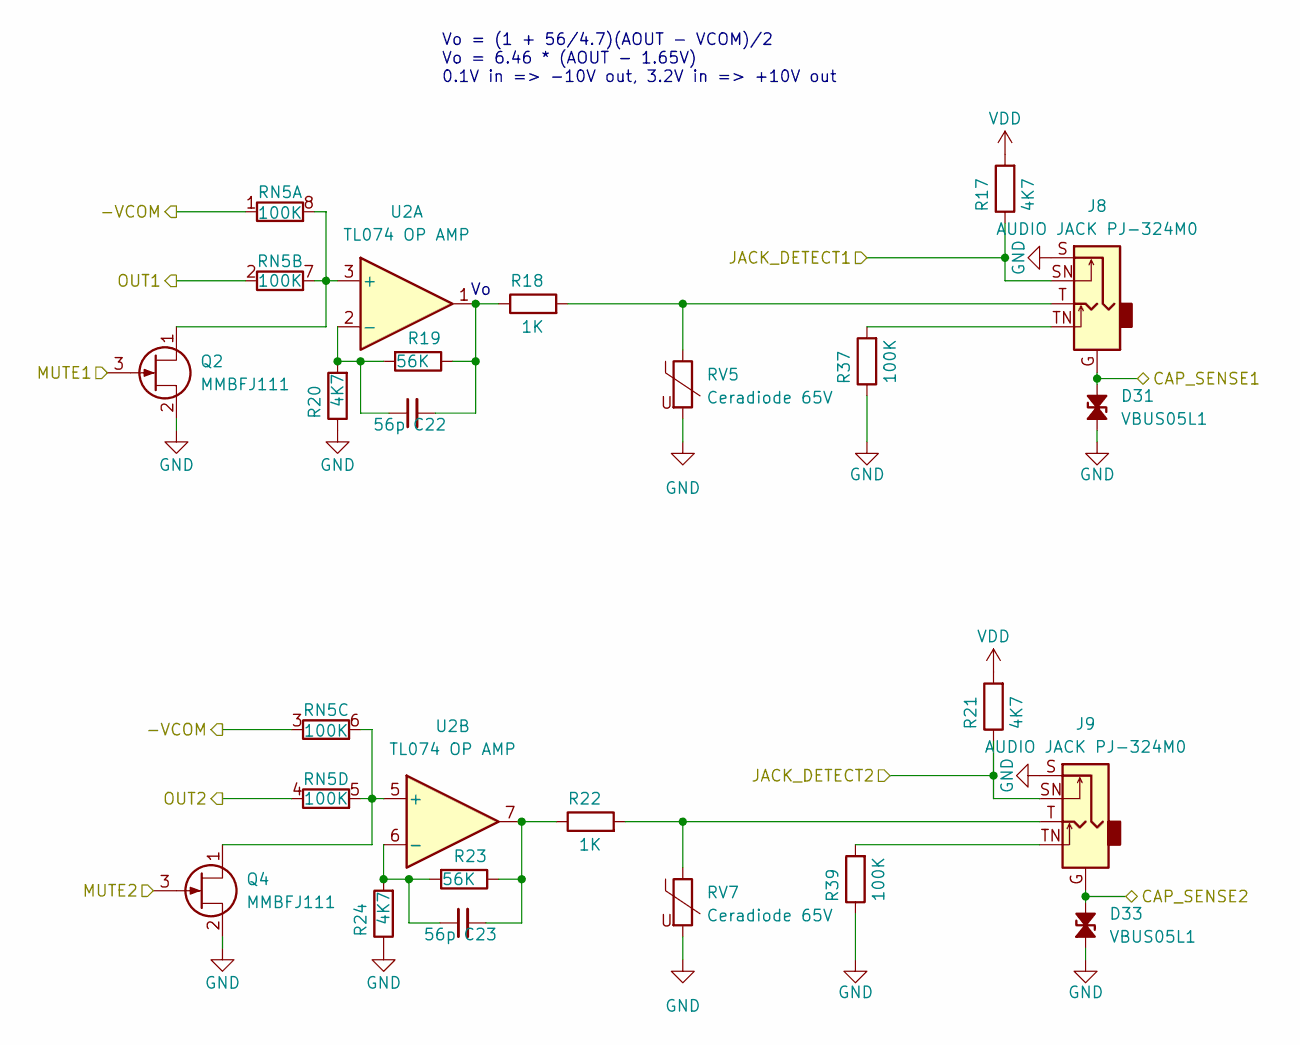
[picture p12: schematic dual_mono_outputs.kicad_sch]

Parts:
C22, C23: 56p; C_0402_1005Metric; mfg# CC0402FRNPO9BN560; lcsc# C526981
D31, D33: VBUS05L1; VISHAY-LLP1006-2M; lcsc# C2649891
J8, J9: AUDIO JACK PJ-324M0; pj324m; mfg# PJ-324M0; lcsc# C2884986
Q2, Q4: MMBFJ111; SOT-23; LCSC C274688
R17, R20, R21, R24: 4K7; R_0402_1005Metric; mfg# RC0402FR-074K7L; lcsc# C105871
R18, R22: 1K; R_0603_1608Metric; mfg# RC0603FR-071KL; lcsc# C22548
R19, R23: 56K; R_0402_1005Metric; mfg# RC0402FR-0756KL; lcsc# C114756
R37, R39: 100K; R_0603_1608Metric; mfg# RC0603FR-07100KL; lcsc# C14675
RN5: 100K; R_Array_Convex_4x0402; mfg# YC124-FR-07100KL; lcsc# C326786
RV5, RV7: Ceradiode 65V; C_0603_1608Metric; lcsc# C210791
U2: TL074 OP AMP; SOIC-14_3.9x8.7mm_P1.27mm; mfg# TL074CDT; lcsc# C6963

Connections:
/-VCOM: RN5.1 (R1.1), RN5.3 (R3.1); also elsewhere on the board
/CAP_SENSE_OUT1: D31.2 (A2), J8.G; also elsewhere on the board
/CAP_SENSE_OUT2: D33.2 (A2), J9.G; also elsewhere on the board
/JACK_DETECT_OUT1: J8.SN, R17.1; also elsewhere on the board
/JACK_DETECT_OUT2: J9.SN, R21.1; also elsewhere on the board
/OUT_MUTE1: Q2.3 (G), Q4.3 (G); also elsewhere on the board
/dual_mono_outputs1/OUT1: RN5.2 (R2.1); also elsewhere on the board
/dual_mono_outputs1/OUT2: RN5.4 (R4.1); also elsewhere on the board
GND: D31.1 (A1), D33.1 (A1), J8.S, J9.S, Q2.2 (S), Q4.2 (S), R20.1, R24.1, R37.1, R39.1, RV5.2, RV7.2; also elsewhere on the board
unnamed: C22.2, R18.1, R19.1, U2.1
unnamed: C23.2, R22.1, R23.1, U2.7
unnamed 42: U2.8; also elsewhere on the board
unnamed 43: U2.14; also elsewhere on the board
unnamed: J8.T, R18.2, RV5.1
unnamed: J8.TN, R37.2
unnamed: J9.T, R22.2, RV7.1
unnamed: J9.TN, R39.2
unnamed: Q2.1 (D), RN5.7 (R2.2), RN5.8 (R1.2), U2.3 (+)
unnamed 95: U2.10 (+); also elsewhere on the board
unnamed: Q4.1 (D), RN5.5 (R4.2), RN5.6 (R3.2), U2.5 (+)
unnamed 97: U2.12 (+); also elsewhere on the board
unnamed: C22.1, R19.2, R20.2, U2.2 (-)
unnamed: C23.1, R23.2, R24.2, U2.6 (-)
unnamed 128: U2.9 (-); also elsewhere on the board
unnamed 129: U2.13 (-); also elsewhere on the board
VDD: R17.2, R21.2; also elsewhere on the board

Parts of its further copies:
C24, C25: 56p; C_0402_1005Metric; mfg# CC0402FRNPO9BN560; lcsc# C526981
D32, D34: VBUS05L1; VISHAY-LLP1006-2M; lcsc# C2649891
J10, J11: AUDIO JACK PJ-324M0; pj324m; mfg# PJ-324M0; lcsc# C2884986
Q3, Q5: MMBFJ111; SOT-23; LCSC C274688
R25, R28, R29, R32: 4K7; R_0402_1005Metric; mfg# RC0402FR-074K7L; lcsc# C105871
R26, R30: 1K; R_0603_1608Metric; mfg# RC0603FR-071KL; lcsc# C22548
R27, R31: 56K; R_0402_1005Metric; mfg# RC0402FR-0756KL; lcsc# C114756
R38, R40: 100K; R_0603_1608Metric; mfg# RC0603FR-07100KL; lcsc# C14675
RN6: 100K; R_Array_Convex_4x0402; mfg# YC124-FR-07100KL; lcsc# C326786
RV6, RV8: Ceradiode 65V; C_0603_1608Metric; lcsc# C210791

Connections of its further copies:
/-VCOM: RN6.1 (R1.1), RN6.3 (R3.1); also elsewhere on the board
/CAP_SENSE_OUT3: D32.2 (A2), J10.G; also elsewhere on the board
/CAP_SENSE_OUT4: D34.2 (A2), J11.G; also elsewhere on the board
/JACK_DETECT_OUT3: J10.SN, R25.1; also elsewhere on the board
/JACK_DETECT_OUT4: J11.SN, R29.1; also elsewhere on the board
/OUT_MUTE1: Q3.3 (G), Q5.3 (G); also elsewhere on the board
/dual_mono_outputs2/OUT1: RN6.2 (R2.1); also elsewhere on the board
/dual_mono_outputs2/OUT2: RN6.4 (R4.1); also elsewhere on the board
GND: D32.1 (A1), D34.1 (A1), J10.S, J11.S, Q3.2 (S), Q5.2 (S), R28.1, R32.1, R38.1, R40.1, RV6.2, RV8.2; also elsewhere on the board
unnamed 42: C24.2, R26.1, R27.1; also elsewhere on the board
unnamed 43: C25.2, R30.1, R31.1; also elsewhere on the board
unnamed: J10.T, R26.2, RV6.1
unnamed: J10.TN, R38.2
unnamed: J11.T, R30.2, RV8.1
unnamed: J11.TN, R40.2
unnamed 95: Q3.1 (D), RN6.7 (R2.2), RN6.8 (R1.2); also elsewhere on the board
unnamed 97: Q5.1 (D), RN6.5 (R4.2), RN6.6 (R3.2); also elsewhere on the board
unnamed 128: C24.1, R27.2, R28.2; also elsewhere on the board
unnamed 129: C25.1, R31.2, R32.2; also elsewhere on the board
VDD: R25.2, R29.2; also elsewhere on the board

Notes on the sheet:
Vo = (1 + 56/4.7)(AOUT - VCOM)/2 Vo = 6.46 * (AOUT - 1.65V) 0.1V in => -10V out, 3.2V in => +10V out

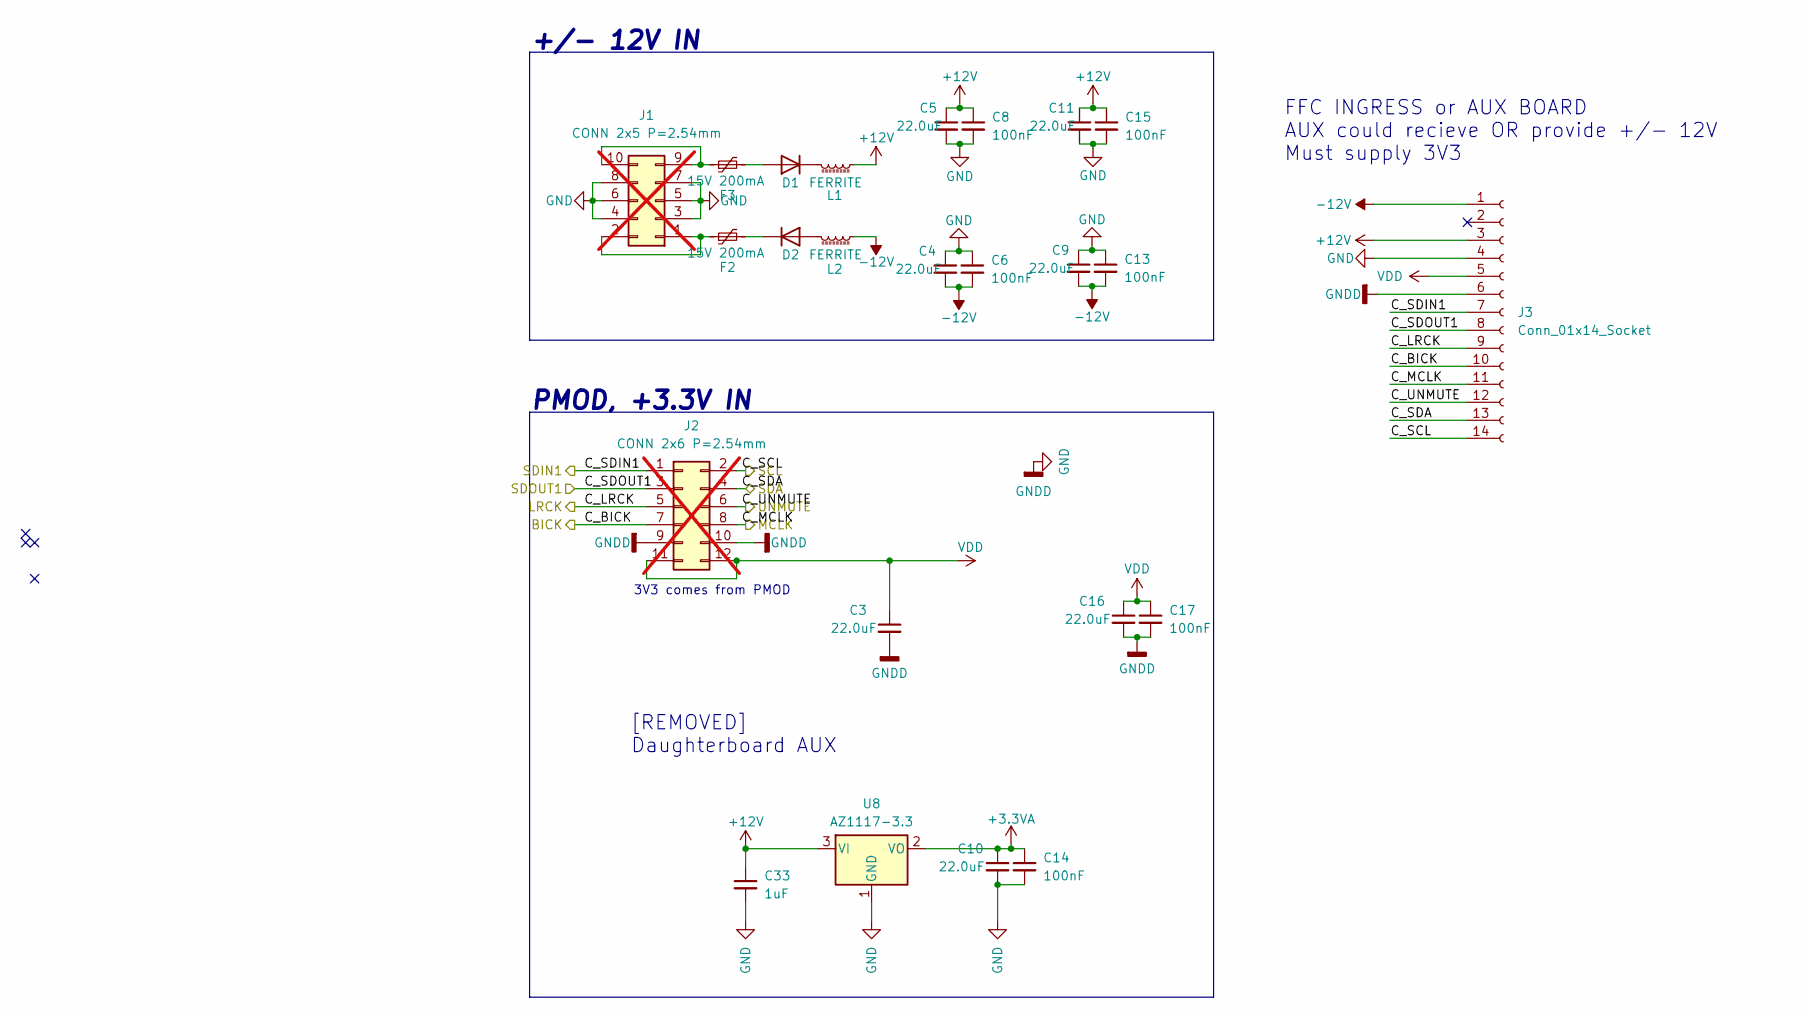
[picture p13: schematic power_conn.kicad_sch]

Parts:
C3: 22.0uF; C_1206_3216Metric; lcsc# C12891
C4, C5, C9, C11: 22.0uF; C_1206_3216Metric; mfg# CA45-A-16V-22uF-K; lcsc# C12891
C6, C8, C13, C14, C15, C17: 100nF; C_0603_1608Metric; mfg# C1608X7R1E104KT000N; lcsc# C338036
C10, C16: 22.0uF; C_1206_3216Metric; mfg# TLJA107M006R0800; lcsc# C12891
C33: 1uF; C_0805_2012Metric; LCSC C28323
D1, D2: Nexperia PMEG6010CEH,115; D_SOD-123F; mfg# Nexperia PMEG6010CEH,115; lcsc# C110797
F2, F3: 15V 200mA; Fuse_0805_2012Metric; lcsc# C883103
J1: CONN 2x5 P=2.54mm; PinHeader_2x05_P2.54mm_Horizontal; mfg# PZ254R-12-10P; lcsc# C492433; not fitted
J2: CONN 2x6 P=2.54mm; PinHeader_2x06_P2.54mm_Horizontal; mfg# PZ254-2-06-W-8.5; lcsc# C2894986; not fitted
J3: Conn_01x14_Socket; FFC_0.5-14P_CTXJ-H2.0_1; mfg# FH12-14S-0.5SH(55); lcsc# C5373472
L1, L2: FERRITE; L_0603_1608Metric; mfg# BLM18PG121SN1D; lcsc# C14709
U8: AZ1117-3.3; SOT-89-3; lcsc# C460428

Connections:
+3.3VA: C10.1, C14.1, U8.2 (VO); also elsewhere on the board
+12V: C5.1, C8.1, C11.1, C15.1, C33.1, J3.3, L1.1, U8.3 (VI); also elsewhere on the board
-12V: C4.2, C6.2, C9.2, C13.2, J3.1, L2.1; also elsewhere on the board
/BICK: J2.7, J3.10; also elsewhere on the board
/LRCK: J2.5, J3.9; also elsewhere on the board
/MCLK: J2.8, J3.11; also elsewhere on the board
/SCL: J2.2, J3.14; also elsewhere on the board
/SDA: J2.4, J3.13; also elsewhere on the board
/SDIN1: J2.1, J3.7; also elsewhere on the board
/SDOUT1: J2.3, J3.8; also elsewhere on the board
/UNMUTE: J2.6, J3.12; also elsewhere on the board
GND: C3.2, C4.1, C5.2, C6.1, C8.2, C9.1, C10.2, C11.2, C13.1, C14.2, C15.2, C16.2, C17.2, C33.2, J1.3, J1.4, J1.5, J1.6, J1.7, J1.8, J2.9, J2.10, J3.4, J3.6, U8.1 (GND); also elsewhere on the board
unnamed: D1.2 (A), F3.2
unnamed: D1.1 (K), L1.2
unnamed: D2.2 (A), L2.2
unnamed: D2.1 (K), F2.2
unnamed: F2.1, J1.1, J1.2
unnamed: F3.1, J1.9, J1.10
VDD: C3.1, C16.1, C17.1, J2.11, J2.12, J3.5; also elsewhere on the board

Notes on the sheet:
+/- 12V IN
PMOD, +3.3V IN
3V3 comes from PMOD
[REMOVED] Daughterboard AUX
FFC INGRESS or AUX BOARD AUX could recieve OR provide +/- 12V Must supply 3V3

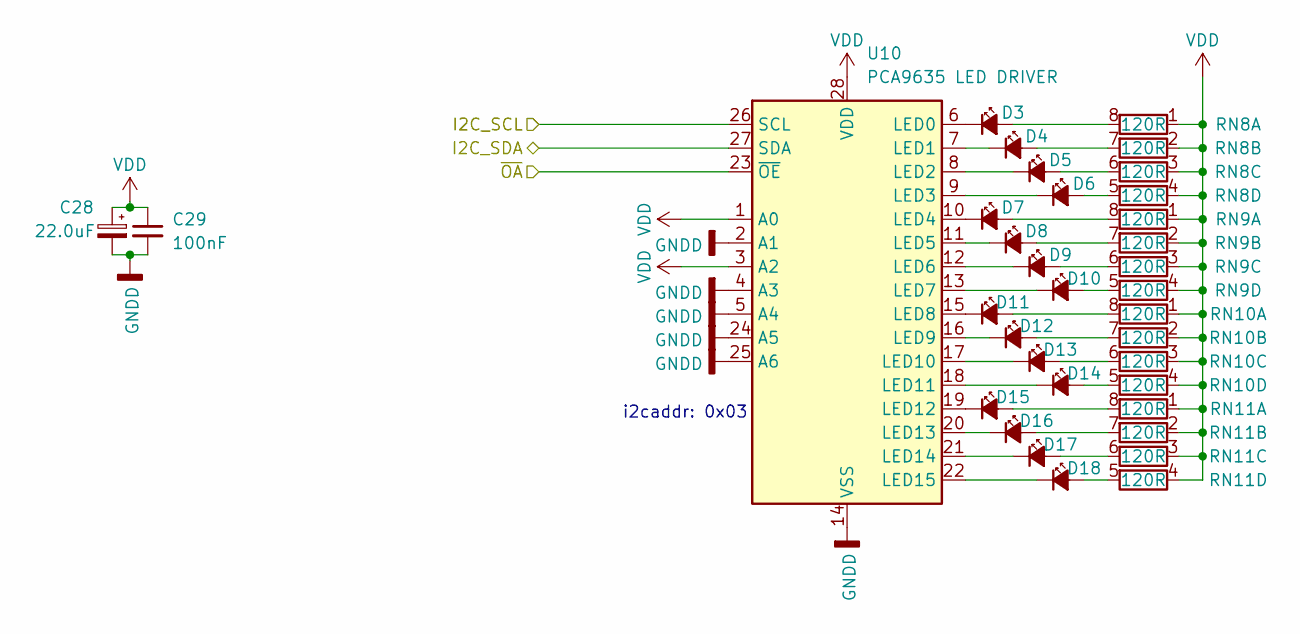
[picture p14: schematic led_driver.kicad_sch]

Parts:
C28: 22.0uF; C_1206_3216Metric; mfg# TLJA107M006R0800; lcsc# C12891
C29: 100nF; C_0603_1608Metric; mfg# C1608X7R1E104KT000N; lcsc# C338036
D3, D5, D7, D9, D11, D13, D15, D17: LED 0402 GREEN; LED_0402_1005Metric; mfg# XL-1005UGC; lcsc# C2856703
D4, D6, D8, D10, D12, D14, D16, D18: LED 0402 RED; LED_0402_1005Metric; mfg# XL-1005SURC; lcsc# C965790
RN8, RN9, RN10, RN11: 120R; R_Array_Convex_4x0402; mfg# YC124-JR-07120RL; lcsc# C326871
U10: PCA9635 LED DRIVER; TSSOP-28_4.4x9.7mm_P0.65mm; mfg# PCA9635PW,118; lcsc# C110795

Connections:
/SCL: U10.26 (SCL); also elsewhere on the board
/SDA: U10.27 (SDA); also elsewhere on the board
/~PDN: U10.23 (~OE); also elsewhere on the board
GND: C28.2, C29.2, U10.2 (A1), U10.4 (A3), U10.5 (A4), U10.14 (VSS), U10.24 (A5), U10.25 (A6); also elsewhere on the board
unnamed: D3.2 (A), RN8.8 (R1.2)
unnamed: D3.1 (K), U10.6 (LED0)
unnamed: D4.2 (A), RN8.7 (R2.2)
unnamed: D4.1 (K), U10.7 (LED1)
unnamed: D5.2 (A), RN8.6 (R3.2)
unnamed: D5.1 (K), U10.8 (LED2)
unnamed: D6.2 (A), RN8.5 (R4.2)
unnamed: D6.1 (K), U10.9 (LED3)
unnamed: D7.2 (A), RN9.8 (R1.2)
unnamed: D7.1 (K), U10.10 (LED4)
unnamed: D8.2 (A), RN9.7 (R2.2)
unnamed: D8.1 (K), U10.11 (LED5)
unnamed: D9.2 (A), RN9.6 (R3.2)
unnamed: D9.1 (K), U10.12 (LED6)
unnamed: D10.2 (A), RN9.5 (R4.2)
unnamed: D10.1 (K), U10.13 (LED7)
unnamed: D11.2 (A), RN10.8 (R1.2)
unnamed: D11.1 (K), U10.15 (LED8)
unnamed: D12.2 (A), RN10.7 (R2.2)
unnamed: D12.1 (K), U10.16 (LED9)
unnamed: D13.2 (A), RN10.6 (R3.2)
unnamed: D13.1 (K), U10.17 (LED10)
unnamed: D14.2 (A), RN10.5 (R4.2)
unnamed: D14.1 (K), U10.18 (LED11)
unnamed: D15.2 (A), RN11.8 (R1.2)
unnamed: D15.1 (K), U10.19 (LED12)
unnamed: D16.2 (A), RN11.7 (R2.2)
unnamed: D16.1 (K), U10.20 (LED13)
unnamed: D17.2 (A), RN11.6 (R3.2)
unnamed: D17.1 (K), U10.21 (LED14)
unnamed: D18.2 (A), RN11.5 (R4.2)
unnamed: D18.1 (K), U10.22 (LED15)
VDD: C28.1, C29.1, RN8.1 (R1.1), RN8.2 (R2.1), RN8.3 (R3.1), RN8.4 (R4.1), RN9.1 (R1.1), RN9.2 (R2.1), RN9.3 (R3.1), RN9.4 (R4.1), RN10.1 (R1.1), RN10.2 (R2.1), RN10.3 (R3.1), RN10.4 (R4.1), RN11.1 (R1.1), RN11.2 (R2.1), RN11.3 (R3.1), RN11.4 (R4.1), U10.1 (A0), U10.3 (A2), U10.28 (VDD); also elsewhere on the board

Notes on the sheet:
i2caddr: 0x03

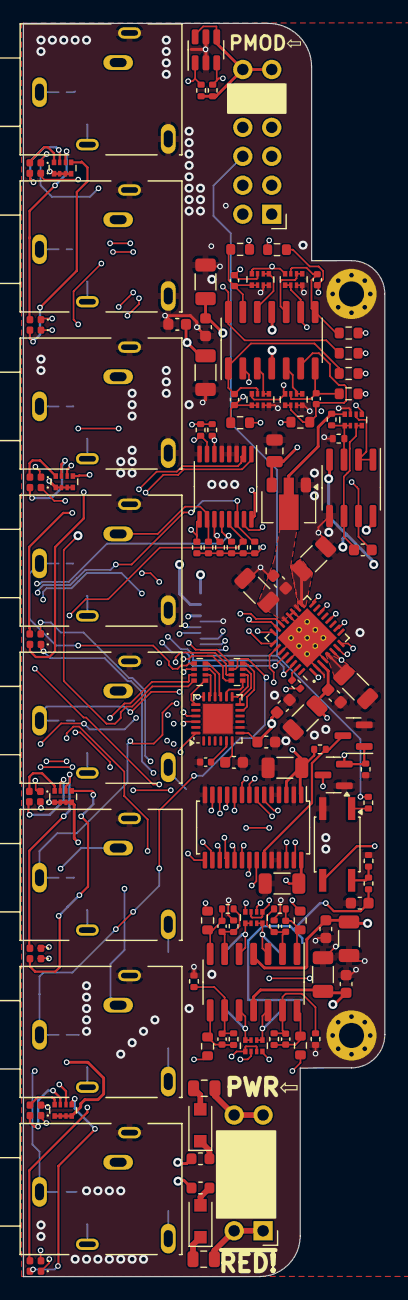
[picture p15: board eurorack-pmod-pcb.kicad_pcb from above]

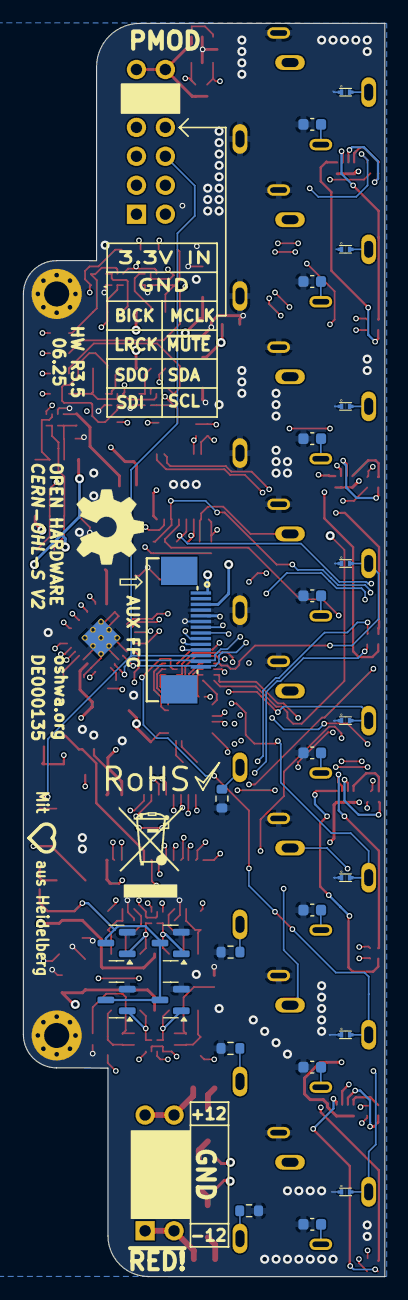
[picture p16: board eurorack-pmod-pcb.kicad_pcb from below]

Board: 6 copper layers, 31.7 x 110.0 mm, 153 parts (25 on the bottom side), 133 nets.

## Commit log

2025-03-30 - Swap stackup s/4/6 - Was: GND/SIG/SIG/GND - Now: GND/VDD/SIG/SIG/GND/GND - Swap CY8CMBR3108 for CY8CMBR3116 - Touch indices do NOT match previous revision. - TODO revise new pinout (XRES) - Combine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
    [dual_mono_inputs.kicad_sch, dual_mono_outputs.kicad_sch, eurorack-pmod-pcb.kicad_pcb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]
2025-03-30 - add poly/pour on +AVDD
    [eurorack-pmod-pcb.kicad_pcb]
2025-03-30 - Add ceradiodes to audio ins/outs - Add low-capacitance TVS to touch channels (TODO footprint)
    [dual_mono_inputs.kicad_sch, dual_mono_outputs.kicad_sch, eurorack-pmod-pcb.kicad_pcb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]
2025-03-31 - ceradiodes/tvs: place and route
    [dual_mono_inputs.kicad_sch, dual_mono_outputs.kicad_sch, eurorack-pmod-pcb.kicad_pcb]
2025-03-31 - Swap all tantalums for ceramics
    [eurorack-pmod-pcb.kicad_pcb, eurorack-pmod-pcb.kicad_sch, led_driver.kicad_sch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]
2025-04-01 - touch: fix XRES on CS6 (!!) - mute: start on JFET output mute
    [dual_mono_outputs.kicad_sch, eurorack-pmod-pcb.kicad_sch]
2025-04-02 vref: replace +3.0V with local 12V->3.3V LDO
    [dual_mono_inputs.kicad_sch, dual_mono_outputs.kicad_sch, eurorack-pmod-pcb.kicad_pcb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]
2025-04-02 ingress: add 200mA polyfuses
    [eurorack-pmod-pcb.kicad_pcb, power_conn.kicad_sch]
2025-04-05 PDN/UNMUTE: add reset IC to PDN, swap PDN/UNMUTE ingress, add opto to UNMUTE
    [eurorack-pmod-pcb.kicad_pcb, eurorack-pmod-pcb.kicad_sch, power_conn.kicad_sch]
2025-04-05 place new parts
    [eurorack-pmod-pcb.kicad_pcb, vref.kicad_sch]
2025-04-26 fab 26.04
    [BOM-eurorack-pmod-pcb.csv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]
2025-05-30 r3.5: add 100k output terminations and 100nF vref filtering, fab outputs (not sent yet)
    [BOM-eurorack-pmod-pcb.csv, dual_mono_outputs.kicad_sch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]
2025-06-22 r3.5: move +/- 12V 1mm in, DNP right angle conns, solid fill mounting holes, add stitching vias, add more labels
    [eurorack-pmod-pcb.kicad_pcb]
2025-06-22 r3.5: DNP vref calibration resistors TODO: double-check this??
    [eurorack-pmod-pcb.kicad_pcb]
2025-06-25 r3.5: update part numbers and fab
    [BOM-eurorack-pmod-pcb.csv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]
2025-06-26 r3.5: move all traces inside 0.4mm edge boundary
    [eurorack-pmod-pcb.kicad_pcb]
2025-06-26 r3.5: fab after reducing edge boundary
    [BOM-eurorack-pmod-pcb.csv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]
2025-11-18 hardware: add R3.5 euro-pmod CAD files for Tiliqua R5.1 release
    [dual_mono_inputs.kicad_sch, dual_mono_outputs.kicad_sch, eurorack-pmod-pcb.kicad_pcb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]
2026-01-28 cal/drivers: fix startup delay / default cal / touch mapping for R3.5 HW

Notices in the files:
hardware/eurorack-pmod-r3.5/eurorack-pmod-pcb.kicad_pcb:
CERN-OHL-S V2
